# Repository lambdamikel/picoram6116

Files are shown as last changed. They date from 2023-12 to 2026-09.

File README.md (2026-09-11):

# picoram6116

A Raspberry Pi Pico (RP2040)-based 6161 SRAM Emulator, SD Card
Interface, and Multi-Expansion for the [Multitech Microprofessor
MPF-1B and MPF-1P SBCs (Single Board
Computers)](https://hackaday.io/project/183618-exploring-the-microprofessor).

Demo videos:

- [PicoRAM 6116 Review by "Mein Elektronik Hobby" (in German)](https://youtu.be/-fE-1R6At-s)

- [John's E&L MT-80Z MPF-1B variant with PicoRAM 6116](https://youtu.be/OmJJHkyRD8g)

- [Microprofessor MPF-1P Z80 PicoRAM 6116 and MPF-1P Printer - The Towers of Hanoi](https://youtu.be/8veR5Y--iOg)

- [Microprofessor MPF-1P Z80 Assembly Programming with PicoRAM 6116 - The Towers of Hanoi](https://youtu.be/II9slfHpY4s)

- [Microprofessor MPG-1(B) Z80 Assembly Programming with PicoRAM 6116 - The Towers of Hanoi](https://youtu.be/KoFRpU5a6iM)

- [PicoRAM 6116 Demo Video with MPF-1B / Rev. 3 PCB](https://youtu.be/Uu-U00VHX-8)

- [PicoRAM 6116 Demo Video with MPF-1P / Rev. 4 PCB](https://youtu.be/QXIxJ-ij4dM)

The [development
logs](https://hackaday.io/project/194092-picoram-6116-sram-emulator-sd-card-interface)
are on [Hackaday.](https://hackaday.com)

This project is a follow-up to [PicoRAM 2090 for the Busch Microtronic
Computer System](https://github.com/lambdamikel/picoram2090); also
see the [development logs on
Hackaday.](https://hackaday.io/project/192655-picoram-2090)

### PicoRAM 6116 with the MPF-1B - older PCB Rev. 3 

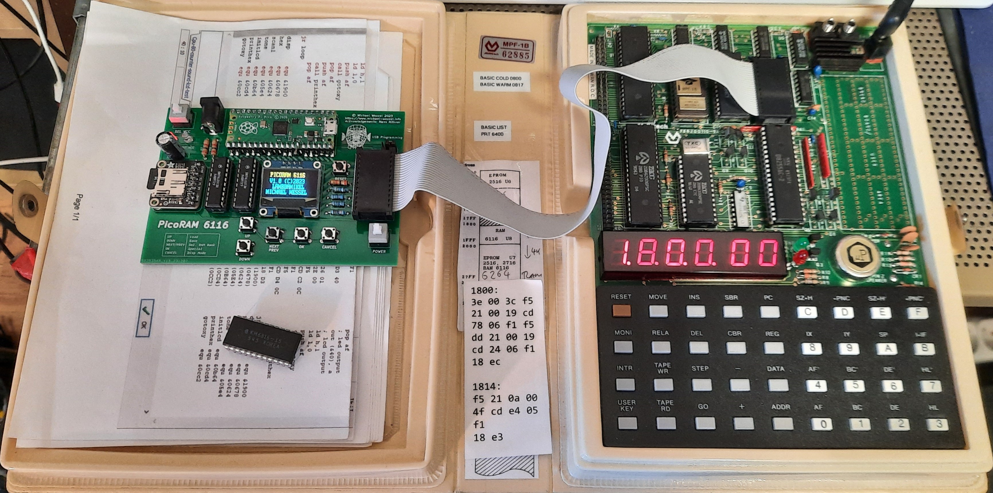
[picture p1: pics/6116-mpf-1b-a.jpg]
PicoRAM 6116 MPF-1B a


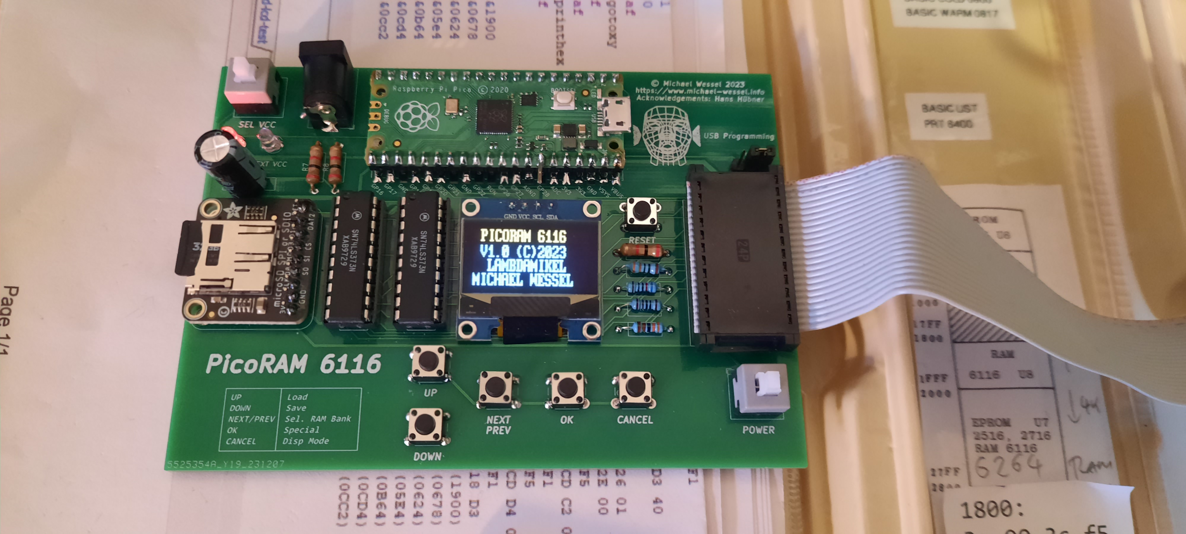
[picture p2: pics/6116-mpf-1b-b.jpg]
PicoRAM 6116 MPF-1B b


### PicoRAM 6116 with the MPF-1P (IP / One Plus) - current PCB Rev. 4 

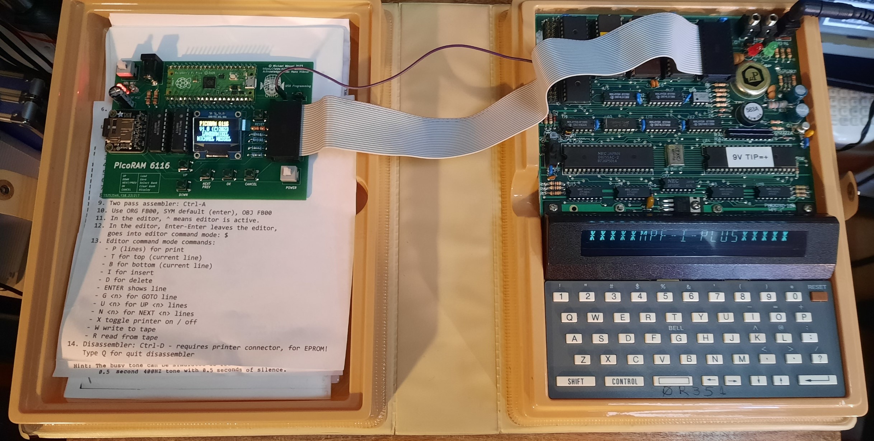
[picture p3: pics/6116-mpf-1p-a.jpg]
PicoRAM 6116 MPF-1P a


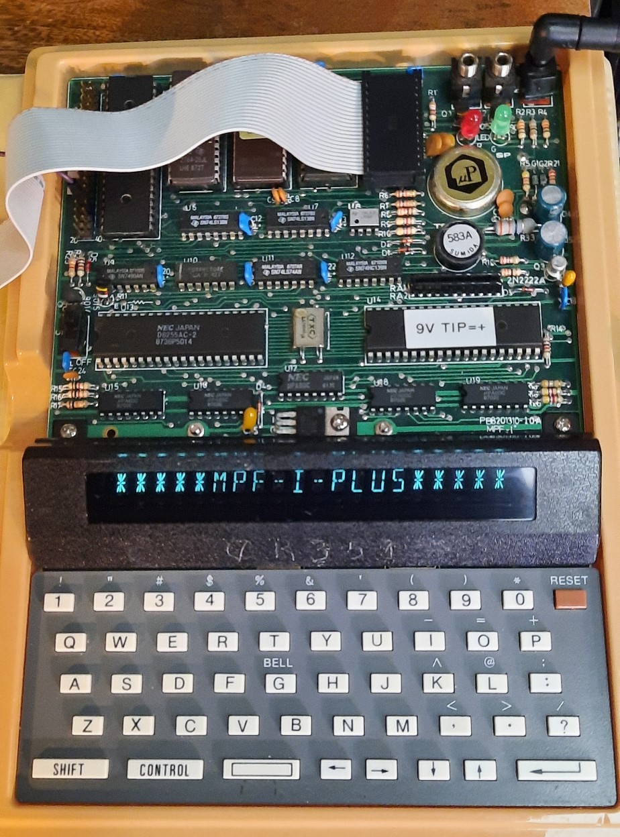
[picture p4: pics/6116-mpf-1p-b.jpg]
PicoRAM 6116 MPF-1P b


## Latest News

### October 2025

During my [RetroChallenge 2025/10
contribution](https://hackaday.io/project/204153-3d-graphics-on-the-microprofessor-mpf-1b),
I encountered a pretty nasty issue which took me quite a while to
debug and resolve. Mostly chasing red herrings. 

My [rotating 3D Cube](https://youtu.be/pLtGfMtQikc) was glitching, and
it took me a long time to realize that this was caused by noisy ADC
button decoding and inappropriate ADC level thresholds. The problem
was that this happened without visual feedback in the UI, so I was
unware of it. Now, for each detected button press, the SRAM emulation
is halted; and also for spurious button presses that don't cause an UI
action (the `CANCEL2` button was responsible). Now, halting the SRAM
emulation can only work properly if the Z80 WAIT signal is connected
to PicoRAM, which I had not in this case. Sometimes, I simply hold the
RESET button manually on the Microprofessor instead whilst operating
PicoRAM. Obviously, you can't just halt SRAM emulation and not halt
the CPU and expect it to run properly.

So, this problem was fixed by adjusting the ADC threshold levels in
the `6116.INI` file. However, I didn't like that the spurious button
presses weren't reported and happened "silently", leaving me unaware
of what was happening. In the UI loop code, there was no `switch case`
that caught this case, and a `default` clause was missing as well. I
have now added such a `default` clause. It will show an error message
on the display informing the user about inadequate ADC button
threshold levels in the init file that may cause SRAM emulation
glitches.

**Please install the [new firmware (Version
1.2).](firmware/sram6116_v1.2.uf2)**

## Older News

### October 2024

[PicoRAM 6116 build and demo video](https://youtu.be/-fE-1R6At-s) on
the YouTube channel "Mein Elektronik Hobby" (in German). Glad it
worked out flawlessly - thanks for the positive review, Werner!

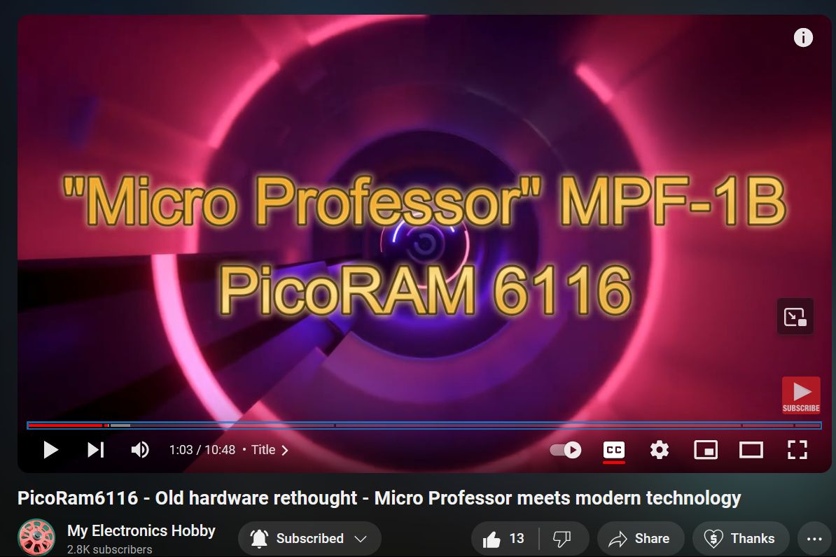
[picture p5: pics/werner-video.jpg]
Werner


### June 2024

John W. added PicoRAM 6116 to his E&L MT-80Z MPF-1B clone and, after
initial troubles, got it to work flawlessly. Very nice machine and 
progress - thanks for sharing, John! Good to know that PicoRAM 6116
also works well with the less common Microprofessor family members.

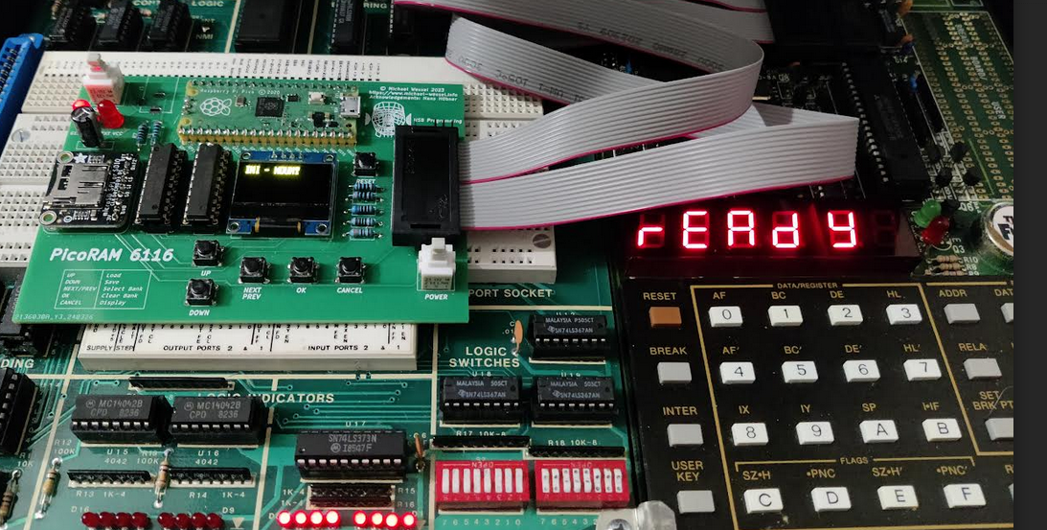
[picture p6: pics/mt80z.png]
MT80Z


### December 17th 2023

[Hackster covered the PicoRAM
6116.](https://www.hackster.io/news/michael-wessel-s-raspberry-pi-pico-powered-6116-sram-emulator-gives-vintage-sbcs-a-major-overhaul-2324810b773c)

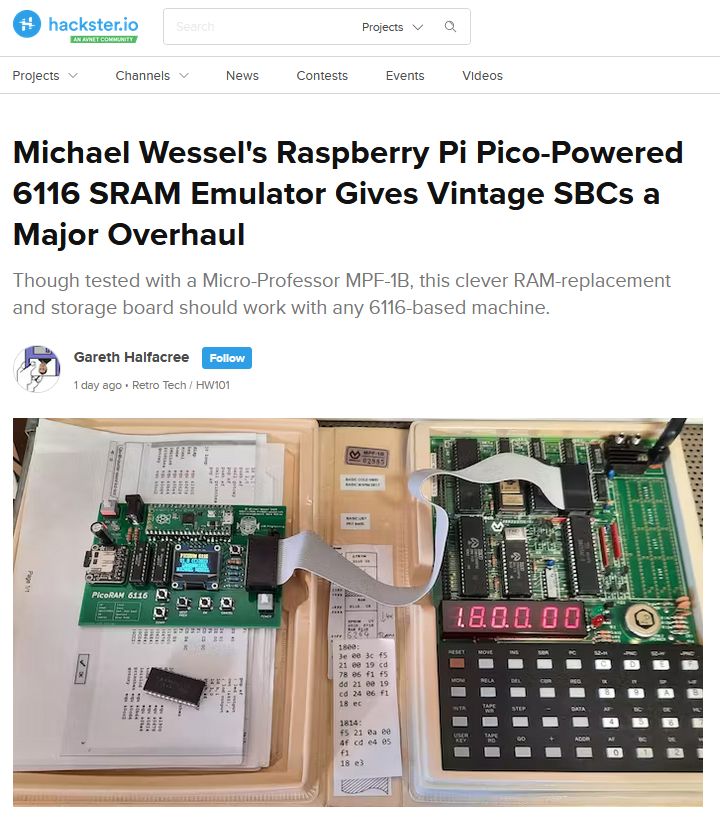
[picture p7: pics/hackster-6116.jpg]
Hackster


I also archived [the PDF of the Hackster article.](pics/hackster-article.pdf)

## About

**PicoRAM 6116 is the ultimate expansion for the vintage Microprofessor SBCs.**

Features:

- SD card interface: loading and saving of programs (full SRAM memory
  dumps) and easy file exchange with the PC (FAT32 filesystem). ASCII
  HEX format, additionally supporting comments and target addresses.

- Plugs into the U8 6116 socket on the MPF-1B
  (address range `0x1800 - 0x1FFF`) or the U5 6116 socket on the MPF-1P
  (address range `0xF800 - 0xFFFF`).

- Comfortable UI: 5 buttons and OLED display.

- 4 user memory banks: the currently active memory bank can selected
  over the UI; each bank hosts a full 6116 SRAM.

- Autoload feature: the `6116.INI` file is loaded during startup
  and allows the specification of an autoload program for each of the 4
  memory banks. 

- Easy build & installation: PicoRAM 6116 uses pre-assembled
  off-the-shelf modules and through-hole components only, and no
  (destructive) modifications to the Microprofessor are required.

## Usage

The JP1 Jumper should be in the right position:

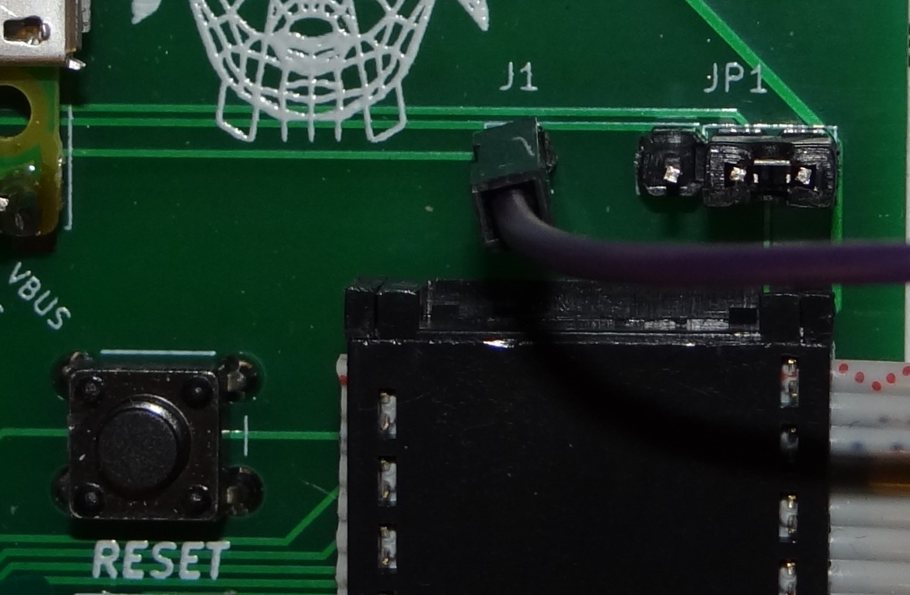
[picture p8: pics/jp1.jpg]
JP1 Jumper


The current version is PCB Rev. 4. This PCB hosts an extra single pin
connector (J1). Connect J1 to the Microprofessor's WAIT on the
expansion header (PIN 37):

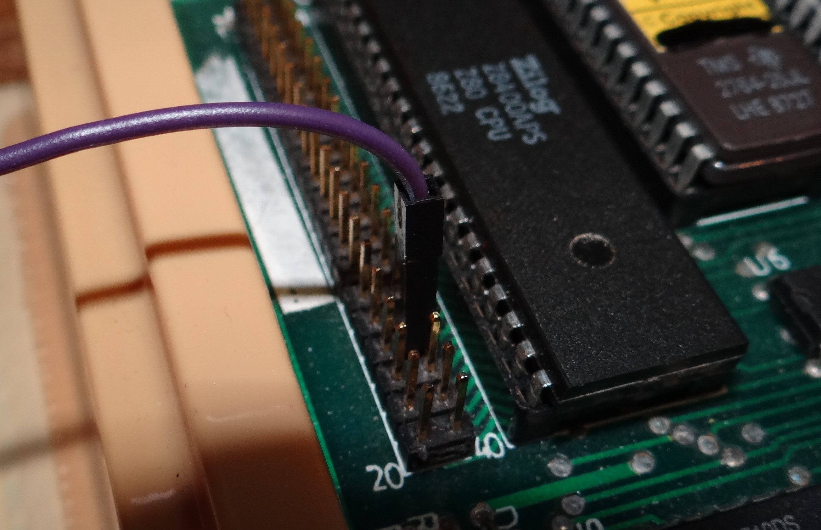
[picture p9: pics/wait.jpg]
WAIT


If you don't use the J1 to WAIT connection, you will need to hold the
Microprofessor in RESET while operating PicoRAM - see the [Rev. 3 Demo
Video](https://youtu.be/Uu-U00VHX-8).  However, this is no longer
required with Rev. 4 (the current version from this repository) - as
shown in [the Rev. 4 demo video](https://youtu.be/QXIxJ-ij4dM)). This
video shows the MPF-1P, but it also applies to the MPF-1B.

PicoRAM needs a FAT32-formatted (max 32 GB) Micro SD Card. Copy the
appropriate `6116.INI` file to it, and get the correct demo programs
for your machine (MPF-1B or MPF-1P). Unzip everything to the root
directory; sub-directories are not supported. See [this
directory.](software/)

PicoRAM 6116 is usually powered over the 6116 SRAM socket. Make sure
that the **POWER** button is pushed down, and that the **SEL VCC**
(Power Source) is set to **6116 VCC**. External power supply is
possible as well, using the 5V Center Positive Barrel Jack. However,
this should not be required. The LEDs **6116 VCC** and **EXT VCC**
light up indicating which power sources are available (i.e., if both
**EXT VCC** and **6116 VCC** light up, it means that you have power
over the 6116 Socket from the Microprofessors, as well as VCC from the
external power supply). Then, use the **SEL VCC** switch to determine
the utilized power source (either external or internal). If you have
an external power source connected, but **EXT VCC** stays dark, then
you probably have the wrong polarity.

### `6116.INI` File

The 5 UI buttons are using the Pico's analog input. Unfortunately, the 
analog levels turned out to be very noisy and also vary from machine
to machine. So it might be necessary for you to "tune" these
analog threshold levels to match your machine. The `6116.INI` file
supports this. The init file looks as follows for the MPF-1B
(not that UNIX EOL is required! a single newline / `0x0A` character):

```
MPF-1B
D00
C00
900
700
300
100
CLOCK.MPF
DICE2.MPF
COUNTER2.MPF
EGGTIME.MPF
0
```

The file lists, in this order:
- the name of the machine
- the analog threshold for the CANCEL buttons (used during YES/NO dialogues) 
- the 2nd analog threshold for the CANCEL buttons (toplevel buttons)
- the analog threshold for the OK button
- the analog threshold for the NEXT/PREV button
- the analog threshold for the UP button
- the analog threshold for the DOWN button
- 4 lines for the 4 autoload programs for banks 0 to 3 - use an empty line for no program
- 0 or 1; 0 for normal operation, and 1 is used to enter a debugging program which can be used to determine the above analog threshold for the buttons above.

Note that the default init files for the MPF-1B and MPF-1P are
supplied, and that the analog thresholds differ. They were determined
with the author's machines, and might not work for your machine.

## Theory of Operation

The Pico emulates the 6116 SRAM of the Microprofessor:

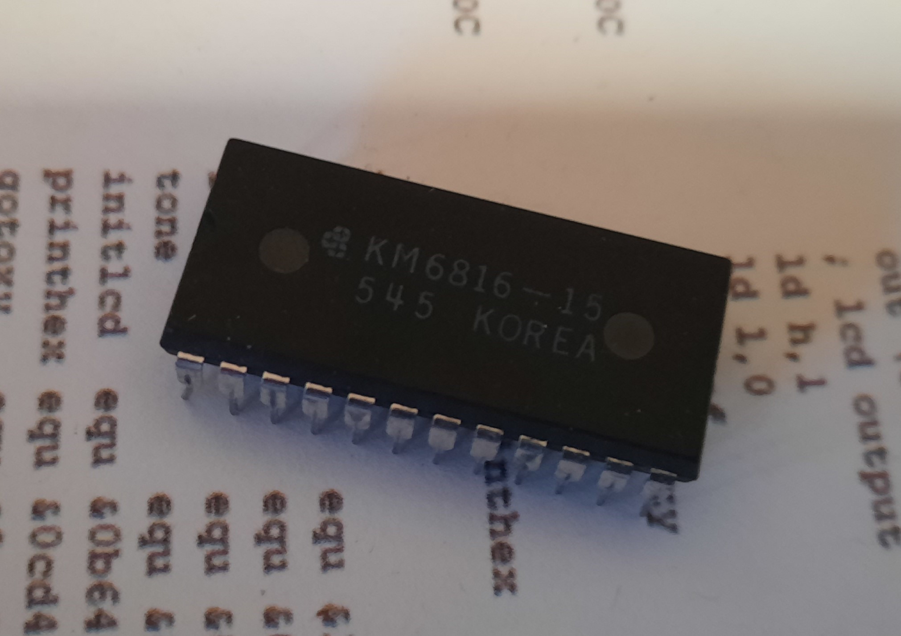
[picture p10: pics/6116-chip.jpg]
6116 Chip


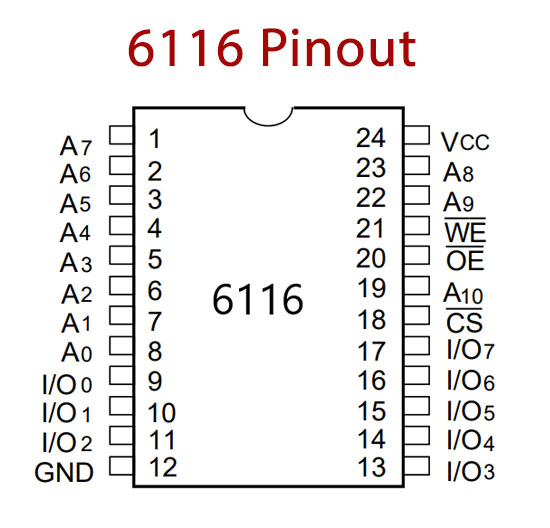
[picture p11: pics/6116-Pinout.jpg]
6116 Pinout


The Pico is overclocked to 250 Mhz to make this possible; this
is completely in the safe range and does not affect the longevity
of the RP2040 in any negative way. 

Due to a lack of GPIOs on the Pico, I used two 74LS373 transparent
octal latches to multiplex the 11-bit address bus. The 11-bit address
is read in two batches of 6 and 5 bits, using the `SEL1` and `SEL2`
signals from the Pico to OE (Output Enable) the first resp. second
latch. The latches are merely used for their tri-state capabilities.

Unlike my previous design, [PicoRAM
2090](https://github.com/lambdamikel/picoram2090), this design does
not utilize any voltage level converters.  It turns out that the Pico
(RP2040) is really pretty much 5V-tolerant; also see [this article
from
Hackaday](https://hackaday.com/2023/04/05/rp2040-and-5v-logic-best-friends-this-fx9000p-confirms/)
and the [Hackaday coverage of PicoRAM
2090.](https://hackaday.com/2023/09/10/pi-pico-becomes-sram-for-1981-educational-computer/)

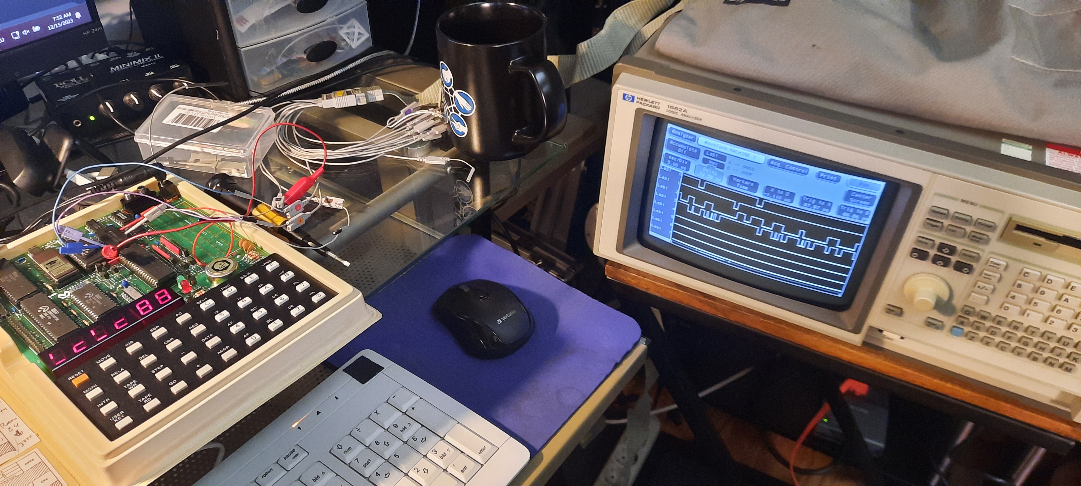
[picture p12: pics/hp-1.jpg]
HP Logic Analyzer 1


More details about the making of the project, and technical notes / development log can be found on the [Hackaday project page.](https://hackaday.io/project/194092-picoram-6116-sram-emulator-sd-card-interface)

Schematics:

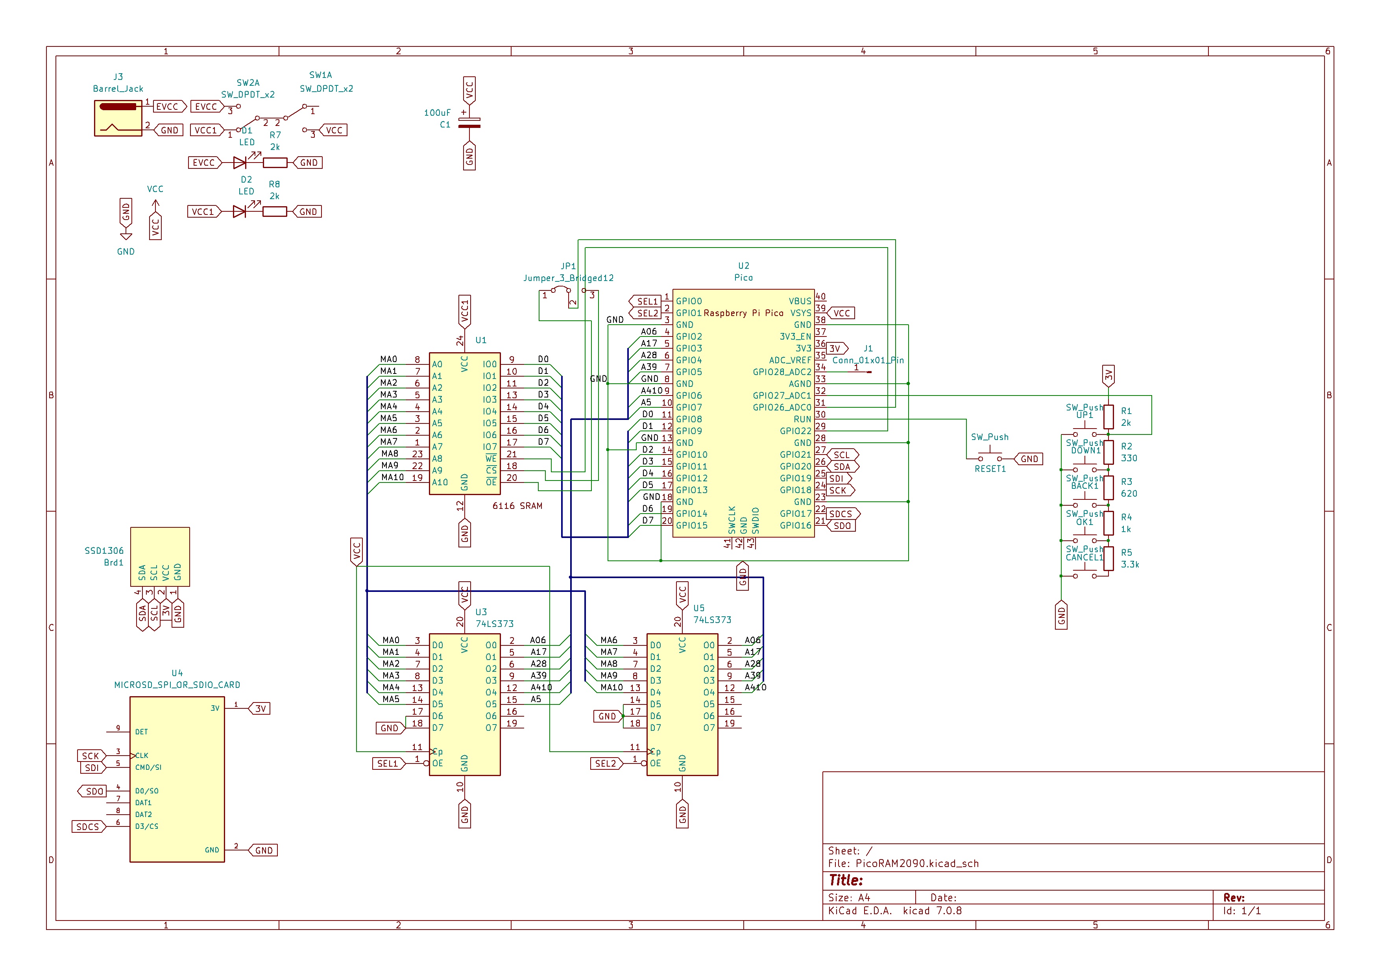
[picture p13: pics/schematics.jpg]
Schematics


## PCB

The current version is Rev. 4, December 2023.

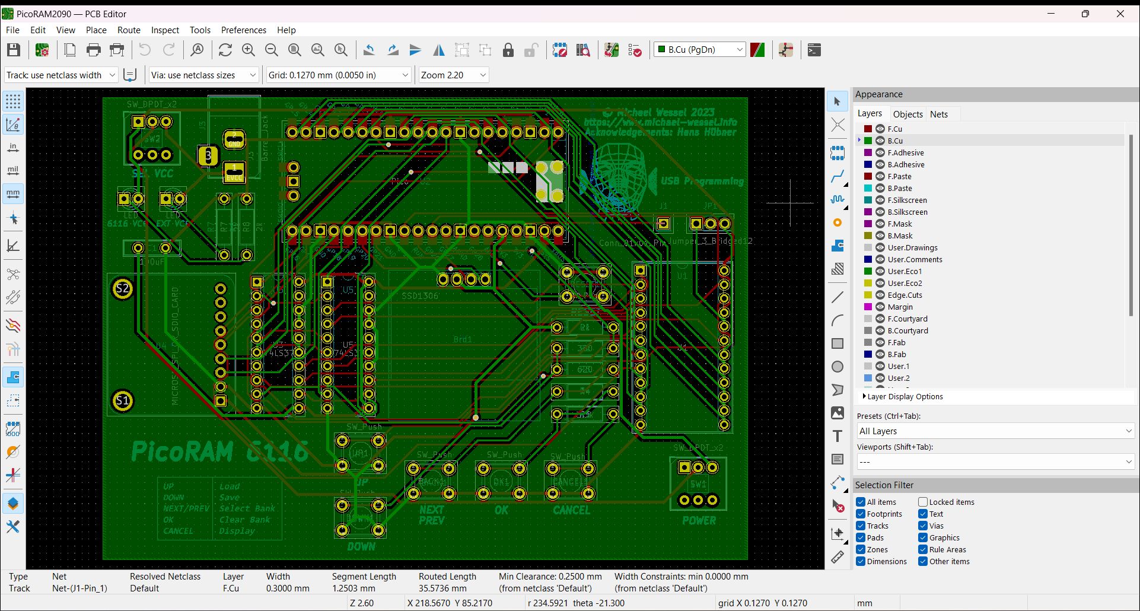
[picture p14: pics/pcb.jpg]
PCB


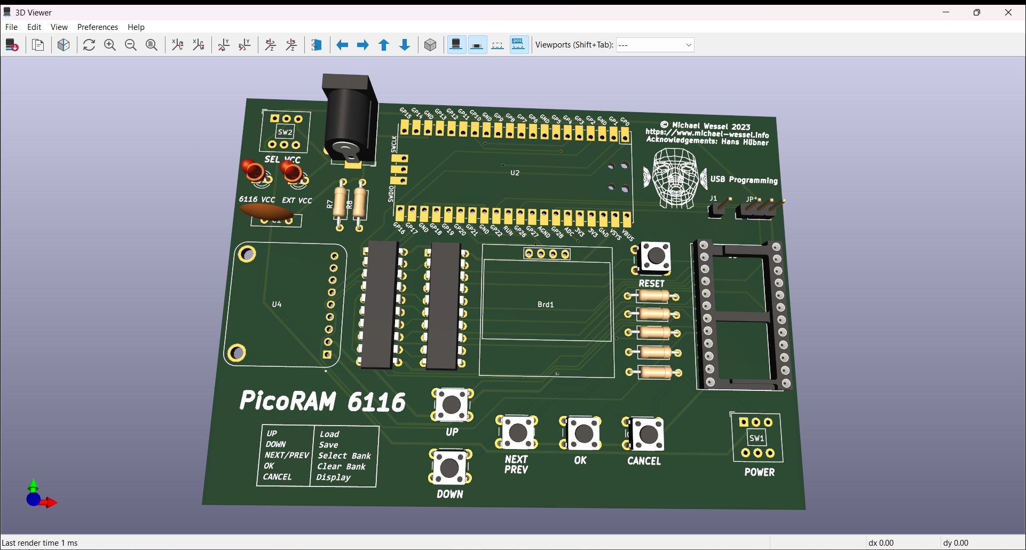
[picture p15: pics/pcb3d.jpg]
PCB 3D


There is also a [Bill of Material (BOM).](gerbers/PicoRAM6116.csv) 

### Gerbers 

See [here.](gerbers/PicoRAM6116-Gerbers.zip) 

## Firmware Image

The current version is 1.1, December 2023 and the `.uf2` image can be
found [here.](firmware/v1.1/sram6116.uf2)

## Firmware Sources

See [here.](src/)

## Acknowledgements

- Harry Fairhead for his [excellent
  book!](https://www.amazon.com/gp/product/1871962056)

- Hans Hübner (aka Pengo) for motivating me to abandon the BluePill,
ATmegas and Arduinos, and for helping to get started and
troubleshooting!

- The authors of the libraries that I am using:

  - Carl J Kugler III carlk3:
    [https://github.com/carlk3/no-OS-FatFS-SD-SPI-RPi-Pico](https://github.com/carlk3/no-OS-FatFS-SD-SPI-RPi-Pico)

  - Raspberry Pi Foundation for the `ssd1306_i2c.c` demo.

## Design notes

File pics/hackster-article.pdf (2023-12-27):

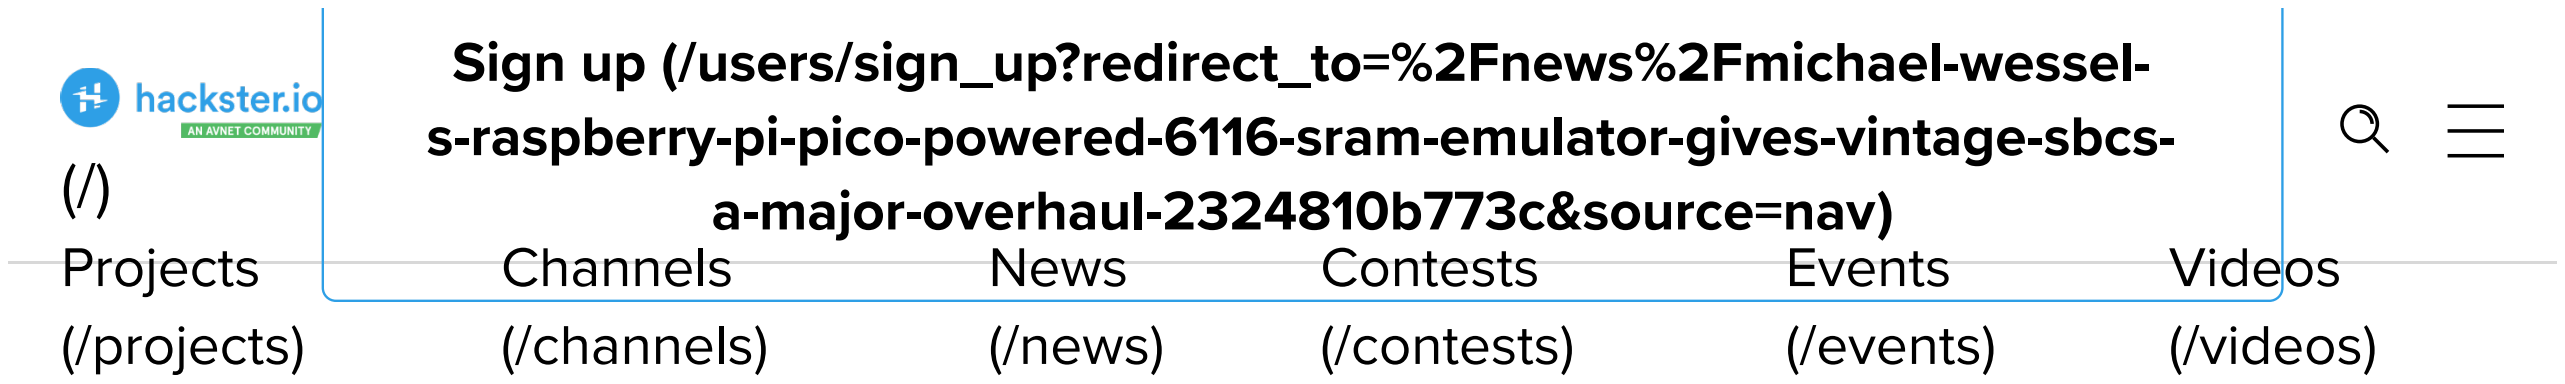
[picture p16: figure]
Sign up (/users/sign_up?redirect_to=%2Fnews%2Fmichael-wessel- s-raspberry-pi-pico-powered-6116-sram-emulator-gives-vintage-sbcs- a-major-overhaul-2324810b773c&source=nav); Projects (/projects); Channels (/channels); News (/news); Contests (/contests); Events (/events); Videos (/videos)

# Michael Wessel's Raspberry Pi Pico-Powered 6116 SRAM Emulator Gives Vintage SBCs a Major Overhaul

## Though tested with a Micro-Professor MPF-1B, this clever RAMreplacement and storage board should work with any 6116-based

machine.

(/ghalfacree)

Gareth Halfacree (/ghalfacree) (https://www.hackster.io/ghalfacree) Follow

1 day ago • Retro Tech (https://www.hackster.io/retrotech) / HW101 (https://www.hackster.io/hw101) (https://www.hackster.io/hw101)

Michael Wessel's Raspberry Pi Pico-Powered 6116 SRAM Emulator Gi... | https://www.hackster.io/news/michael-wessel-s-raspberry-pi-pico-powe...

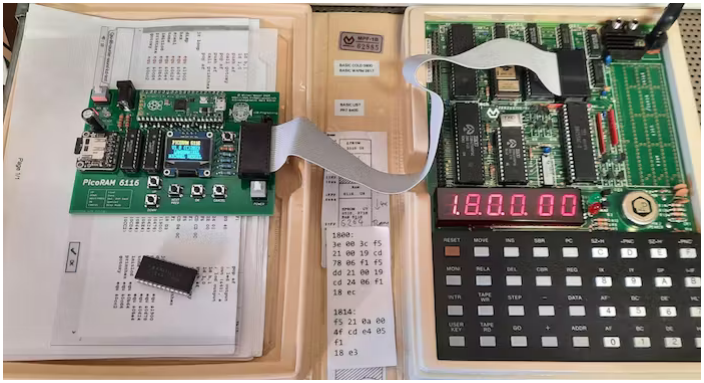
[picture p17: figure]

1 of 8 | 12/19/2023, 6:34 PM

(https://hubs.li/Q02cBMp60)
Ad (http://help.hackster.io/knowledgebase/what-are-these-ads) (http://help.hackster.io/knowledgebase/what-are-these-ads)

Vintage computing enthusiast Michael Wessel has turned a Raspberry Pi Pico into static RAM (SRAM) emulator and SD card storage interface for the Multitech Micro-Professor MPF-1B — bringing with it some serious quality-oflife bonuses.

"Give your Micro-Professor MPF-1B (and other machines) a versatile SD card interface — no more cassettes," Wessel writes of his creation. "Emulate 2kBs of 6116 SRAM with a Raspberry Pi Pico and use an SD card for storing and loading full memory dumps! Its first use case is to emulate the U8 2kB system RAM from 0x1800 to 0x1FFF on the Micro-Professor MPF-1B. You won't need the cassette interface any longer — just use the SD card."

If you've a vintage computer built around 6116 SRAM chips, this Raspberry Pi Pico-powered add-on is exactly what you need. (

: Michael Wessel)

Launched in 1981 by Multitech, which still makes computers today under the more recognizable name Acer, the Micro-Professor MPF-I was a Zilog Z80-based single-board computer which aimed to teach the core concepts of programming for the chip. The device's output was shown on a six-digit seven-segment display, while programs could be saved — slowly — to cassette tape.

It's this slow storage medium Wessel's creation replaces, bypassing the machine's own storage system in order to load and save directly to RAM near-instantaneously — by using a Raspberry Pi Pico's RP2040 microcontroller to emulate the machine's original 2kB RAM chip.

Getting the device up and running proved a challenge — not least of all due to a lack of GPIO pins. (

: Michael Wessel)

"The first challenge was a lack of GPIO [General-Purpose Input/Output] pins on the Pico," Wessel writes of the project. "The 6116 [SRAM chip demands] a whooping eight bits of data IO, 11 bits for the address bus, plus OE [Output Enable] and WE [Write Enable] — 21 GPIOs of the max. 26 that the Pico offers."

Given that Wessel also wanted to offer a user interface with an OLED display, and storage on an SD card slot, additional GPIO pins were required — which were provided through multiplexing the address bus using two 74LS373 eightbit latches. "The two latches are basically just used for their tri-state/High-Z ability," Wessel explains, "I am not even using them as latches."

The device provides the ability to load and save full 2kB memory dumps near-instantaneously from microSD storage. (

: Michael Wessel)

This isn't the first device Wessel has built from a Raspberry Pi Pico in order to offer quality-of-life improvements for vintage computers. Back in September he unveiled an add-on for the Busch 2090 Microtronic Computer System (https://www.hackster.io/news/michael-wessel-turns-a-raspberry-pi-pico-intoan-add-on-for-the-four-bit-busch-2090-microtronic-sbc-c21abaff56bd), (https://www.hackster.io/news/michael-wessel-turns-a-raspberry-pi-pico-into-an-add-on-for-the-four-bit-busch-2090-microtronic-sbc-c21abaff56bd) the PicoRAM 2090, which aimed to work around the device's painfully slow 14-baud cassette interface with microSD storage.

The final device works perfectly on a real Multitech Micro-Professor MPF-1B — even pulling its power from the host system directly — and, Wessel notes, should also work "with other 6116-based computers." More information on the project is available on Wessel's Hackaday.io page (https://hackaday.io/project/194092-picoram-6116-sram-emulator-sd-card-interface). (https://hackaday.io/project/194092-picoram-6116-sram-emulator-sd-card-interface)

sd card (https://www.hackster.io/projects/tags/sd+card)

retro (https://www.hackster.io/projects/tags/retro)

single board computer (https://www.hackster.io/projects/tags/single+board+computer)

microcontroller (https://www.hackster.io/projects/tags/microcontroller)

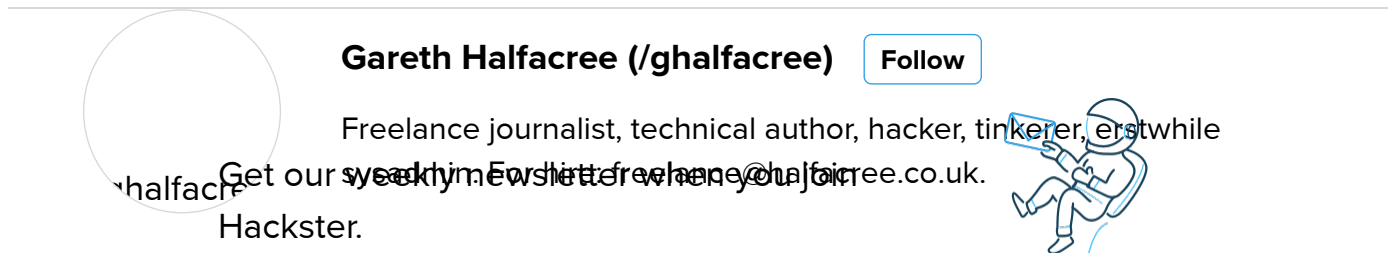
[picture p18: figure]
(/ghalfacree); Gareth Halfacree (/ghalfacree) Follow; sysadmin. For hire: freelance@halfacree.co.uk.; Get our weekly newsletter when you join Hackster.

Freelance journalist, technical author, hacker, tinkerer, erstwhile

SPONSORED ARTICLES

Iván Arakistain Wins the Top Connect for Good Prize for an Emissions-Slashing Nordic nRF9160 Gadget
(https://www.hackster.io/news/ivan-arakistain-wins-the-top-connect-forgood-prize-for-an-emissions-slashing-nordic-nrf9160-gadget-818618ec7ac6) (https://www.hackster.io/news/ivan-arakistain-wins-the-top-connect-for-good-prize-for-an-emissions-slashing-nordic-nrf9160-gadget-818618ec7ac6)
Sponsored by Nordic Semiconductor (https://www.nordicsemi.com)

Revitalizing Nantou Ancient Town: A Co-Creation Adventure (https://www.hackster.io/news/revitalizing-nantou-ancient-town-a-co-creation-adventure-c45f8fc0c7fb) (https://www.hackster.io/news/revitalizing-nantou-ancient-town-a-co-creation-adventure-c45f8fc0c7fb)
Sponsored by Seeed Studio (https://www.seeedstudio.com)

Sign up

LATEST ARTICLES (https://www.hackster.io/news/ivan-arakistain-wins-the-top-connect-for-good-prize-for-an-emissions-slashing-nordic-nrf9160-gadget-818618ec7ac6) | Read more (/news?ref=ha_rm_btn) (https://www.hackster.io/news?ref=ha_rm_btn)

(https://
www.ha
ckster.io (https://www.hackster.io/news/ivan-arakistain-wins-the-top-connect-for-good-prize-for-an-emissions-slashing-nordic-nrf9160-gadget-818618ec7ac6)

(https://
www.ha
ckster.io (https://www.hackster.io/news/revitalizing-nantou-ancient-town-a-co-creation-adventure-c45f8fc0c7fb)

RELATED ARTICLES

Artur Pękosz's Palm-Sized Quadcopter Drone Uses a Single-Camera Raspberry Pi for FPV and Recording (https://www.hackster.io/news/artur-pekosz-s-palm-sized-quadcopterdrone-uses-a-single-camera-raspberry-pi-forfpv-and-recording-27243ca5b27a) (https://www.hackster.io/news/artur-pekosz-s-palm-sized-quadcopter-drone-uses-a-single-camera-raspberry-pi-for-fpv-and-recording-27243ca5b27a)
Gareth Halfacree (/ghalfacree) (https://www.hackster.io/ghalfacree) • 13 hours ago

Sonocotta's Esparagus HiFi MediaLink Puts an Espressif ESP32 to Work Upgrading Your Old Hi-Fi (https://www.hackster.io/news/sonocotta-s-esparagus-hifi-medialinkputs-an-espressif-esp32-to-work-upgradingyour-old-hi-fi-be50297e41ef) (https://www.hackster.io/news/sonocotta-s-esparagus-hifi-medialink-puts-an-espressif-esp32-to-work-upgrading-your-old-hi-fi-be50297e41ef)
Gareth Halfacree (/ghalfacree) (https://www.hackster.io/ghalfacree) • 14 hours ago

This Micro Nissan Micra Is a 1/150th Scale Model That Actually Drives, Thanks to Under-Road Wiring (https://www.hackster.io/news/this-micro-nissan-micra-is-a-1-150thscale-model-that-actually-drives-thanks-tounder-road-wiring-5d7cff6b2c8c) (https://www.hackster.io/news/this-micro-nissan-micra-is-a-1-150th-scale-model-that-actually-drives-thanks-to-under-road-wiring-5d7cff6b2c8c)
Gareth Halfacree (/ghalfacree) (https://www.hackster.io/ghalfacree) • 15 hours ago

A Deep Dive Into Reinforcement Learning (https://www.hackster.io/news/a-deep-diveinto-reinforcement-learning-f1aa70f3276a) (https://www.hackster.io/news/a-deep-dive-into-reinforcement-learning-f1aa70f3276a)
Nick Bild (/nickbild) (https://www.hackster.io/nickbild) • 1 day ago

(https://www.hackster.io/news/arturpekosz-s-palm-sized-quadcopter-droneuses-a-single-camera-raspberry-pi-for-fpvand-recording-27243ca5b27a) (https://www.hackster.io/news/artur-pekosz-s-palm-sized-quadcopter-drone-uses-a-single-camera-raspberry-pi-for-fpv-and-recording-27243ca5b27a)

(https://www.hackster.io/news/sonocottas-esparagus-hifi-medialink-puts-anespressif-esp32-to-work-upgrading-yourold-hi-fi-be50297e41ef) (https://www.hackster.io/news/sonocotta-s-esparagus-hifi-medialink-puts-an-espressif-esp32-to-work-upgrading-your-old-hi-fi-be50297e41ef)

(https://www.hackster.io/news/this-micronissan-micra-is-a-1-150th-scale-modelthat-actually-drives-thanks-to-under-roadwiring-5d7cff6b2c8c) (https://www.hackster.io/news/this-micro-nissan-micra-is-a-1-150th-scale-model-that-actually-drives-thanks-to-under-road-wiring-5d7cff6b2c8c)

(https://www.hackster.io/news/a-deepdive-into-reinforcement-learningf1aa70f3276a) (https://www.hackster.io/news/a-deep-dive-into-reinforcement-learning-f1aa70f3276a)

Matt Callow Turns a Raspberry Pi Pico Into a Low-Cost ROM Emulator for the Amstrad CPC Family (https://www.hackster.io/news/matt-callow-turns-a-raspberry-pi-picointo-a-low-cost-rom-emulator-for-theamstrad-cpc-family-cd82e984b9f8) (https://www.hackster.io/news/matt-callow-turns-a-raspberry-pi-pico-into-a-low-cost-rom-emulator-for-the-amstrad-cpc-family-cd82e984b9f8)
Gareth Halfacree (/ghalfacree) (https://www.hackster.io/ghalfacree) • 8 months ago

Konrad Beckmann's Raspberry Pi Pico-Powered Adapter Gives the Nintendo 64 an HDMI Video Output (https://www.hackster.io/news/konrad-beckmann-s-raspberry-pi-pico-powered-adapter-gives-the-nintendo-64-an-hdmi-video-output-f10600bb3ea5) (https://www.hackster.io/news/konrad-beckmann-s-raspberry-pi-pico-powered-adapter-gives-the-nintendo-64-an-hdmi-video-output-f10600bb3ea5)
Gareth Halfacree (/ghalfacree) (https://www.hackster.io/ghalfacree) • 9 months ago

Raspberry Pi Launches New Debian 12 "Bookworm" Raspberry Pi OS, Ready for Raspberry Pi 5 (https://www.hackster.io/news/raspberry-pi-launches-new-debian-12-bookworm-raspberry-pi-os-ready-forraspberry-pi-5-611ead3e4103) (https://www.hackster.io/news/raspberry-pi-launches-new-debian-12-bookworm-raspberry-pi-os-ready-for-raspberry-pi-5-611ead3e4103)
Gareth Halfacree (/ghalfacree) (https://www.hackster.io/ghalfacree) • 2 months ago (https://www.hackster.io/privacy/ccpa)

An Ultra-Tiny RISC-V Emulator Turns the Raspberry Pi Pico Into a Functional, If Slow, Linux PC (https://www.hackster.io/news/an-ultra-tiny-risc-v-emulator-turns-the-raspberry-pi-pico-into-a-functional-if-slow-linuxpc-17493d4d7130) (https://www.hackster.io/news/an-ultra-tiny-risc-v-emulator-turns-the-raspberry-pi-pico-into-a-functional-if-slow-linux-pc-17493d4d7130)
Gareth Halfacree (/ghalfacree) (https://www.hackster.io/ghalfacree) • 7 months ago

(https://www.hackster.io/news/mattcallow-turns-a-raspberry-pi-pico-intoa-low-cost-rom-emulator-for-the-amstradcpc-family-cd82e984b9f8) (https://www.hackster.io/news/matt-callow-turns-a-raspberry-pi-pico-into-a-low-cost-rom-emulator-for-the-amstrad-cpc-family-cd82e984b9f8)

(https://www.hackster.io/news/konradbeckmann-s-raspberry-pi-pico-poweredadapter-gives-the-nintendo-64-an-hdmivideo-output-f10600bb3ea5) (https://www.hackster.io/news/konrad-beckmann-s-raspberry-pi-pico-powered-adapter-gives-the-nintendo-64-an-hdmi-video-output-f10600bb3ea5)

(https://www.hackster.io/news/raspberry-pi-launches-new-debian-12-bookwormraspberry-pi-os-ready-for-raspberry-pi-5-611ead3e4103) (https://www.hackster.io/news/raspberry-pi-launches-new-debian-12-bookworm-raspberry-pi-os-ready-for-raspberry-pi-5-611ead3e4103)

(https://www.hackster.io/news/an-ultra-tiny-risc-v-emulator-turns-the-raspberry-pi-pico-into-a-functional-if-slow-linuxpc-17493d4d7130) (https://www.hackster.io/news/an-ultra-tiny-risc-v-emulator-turns-the-raspberry-pi-pico-into-a-functional-if-slow-linux-pc-17493d4d7130)

NEXT ARTICLE
Open Melt Is a "Melty Brain" Translatio…

(https://www.hackster.io
/news/open-melt-isa-melty-braintranslational-drift-robotspinning-like-a-remotecontrol-beyblade-8090c801724e (https://www.hackster.io/news/open-melt-is-a-melty-brain-translational-drift-robot-spinning-like-a-remote-control-beyblade-8090c801724e) About Us

Hackster Overview (/about)
Hackster for Business
(/business) (https://www.hackster.io/news/raspberry-pi-launches-new-debian-12-bookworm-raspberry-pi-os-ready-for-raspberry-pi-5-611ead3e4103)
Help Articles (https://www.hackster.io/ghalfacree)
(https://help.hackster.io) Brand Resources (/branding) (https://www.hackster.io/branding) Sitemap (/sitemap.xml.html) (https://www.hackster.io/sitemap.xml.html)

Legal Thingies

Terms of Service (/ter (https://www.hackster.io/news/raspberry-pi-launches-new-debian-12-bookworm-raspberry-pi-os-ready-for-raspberry-pi-5-611ead3e4103)ms) (https://www.hackster.io/terms)
Code of Conduct (/co (https://www.hackster.io/news/raspberry-pi-launches-new-debian-12-bookworm-raspberry-pi-os-ready-for-raspberry-pi-5-611ead3e4103)nduc (https://www.hackster.io/conduct)t) (https://www.hackster.io/news/an-ultra-tiny-risc-v-emulator-turns-the-raspberry-pi-pico-into-a-functional-if-slow-linux-pc-17493d4d7130) Privacy Policy (/privac (https://www.hackster.io/news/raspberry-pi-launches-new-debian-12-bookworm-raspberry-pi-os-ready-for-raspberry-pi-5-611ead3e4103)y) (https://www.hackster.io/privacy)
Privacy Policy for Californi (https://www.hackster.io/privacy/ccpa)a (https://www.hackster.io/ghalfacree) Residents (/privacy/ccpa) (https://www.hackster.io/privacy/ccpa)
Cookie Policy (/cookies) (https://www.hackster.io/cookies)

Find Us On Social

- Facebook
(https://www.facebook.com
/hacksterio) (https://www.hackster.io/news/an-ultra-tiny-risc-v-emulator-turns-the-raspberry-pi-pico-into-a-functional-if-slow-linux-pc-17493d4d7130)
- Instagram (https://www.hackster.io/ghalfacree)
(https://www.instagram.com/hacksterio) (https://www.instagram.com/hacksterio)
- LinkedIn
(https://www.linkedin.com
/company/hacksterio) (https://www.linkedin.com/company/hacksterio)
- Twitter
(https://www.twitter.com
/hacksterio) (https://www.twitter.com/hacksterio)
- YouTube (https://www.youtube.com/hacksterio)

(https://www.youtube.com
/hacksterio) (https://www.youtube.com/hacksterio)

Visit Our Avnet Family

Avnet (https://www.avnet.com) Premier Farnell
(https://www.farnell.com)
element14
(https://www.element14.com)
Newark
(https://www.newark.com) | Hackster.io, an Avnet Community © 2023

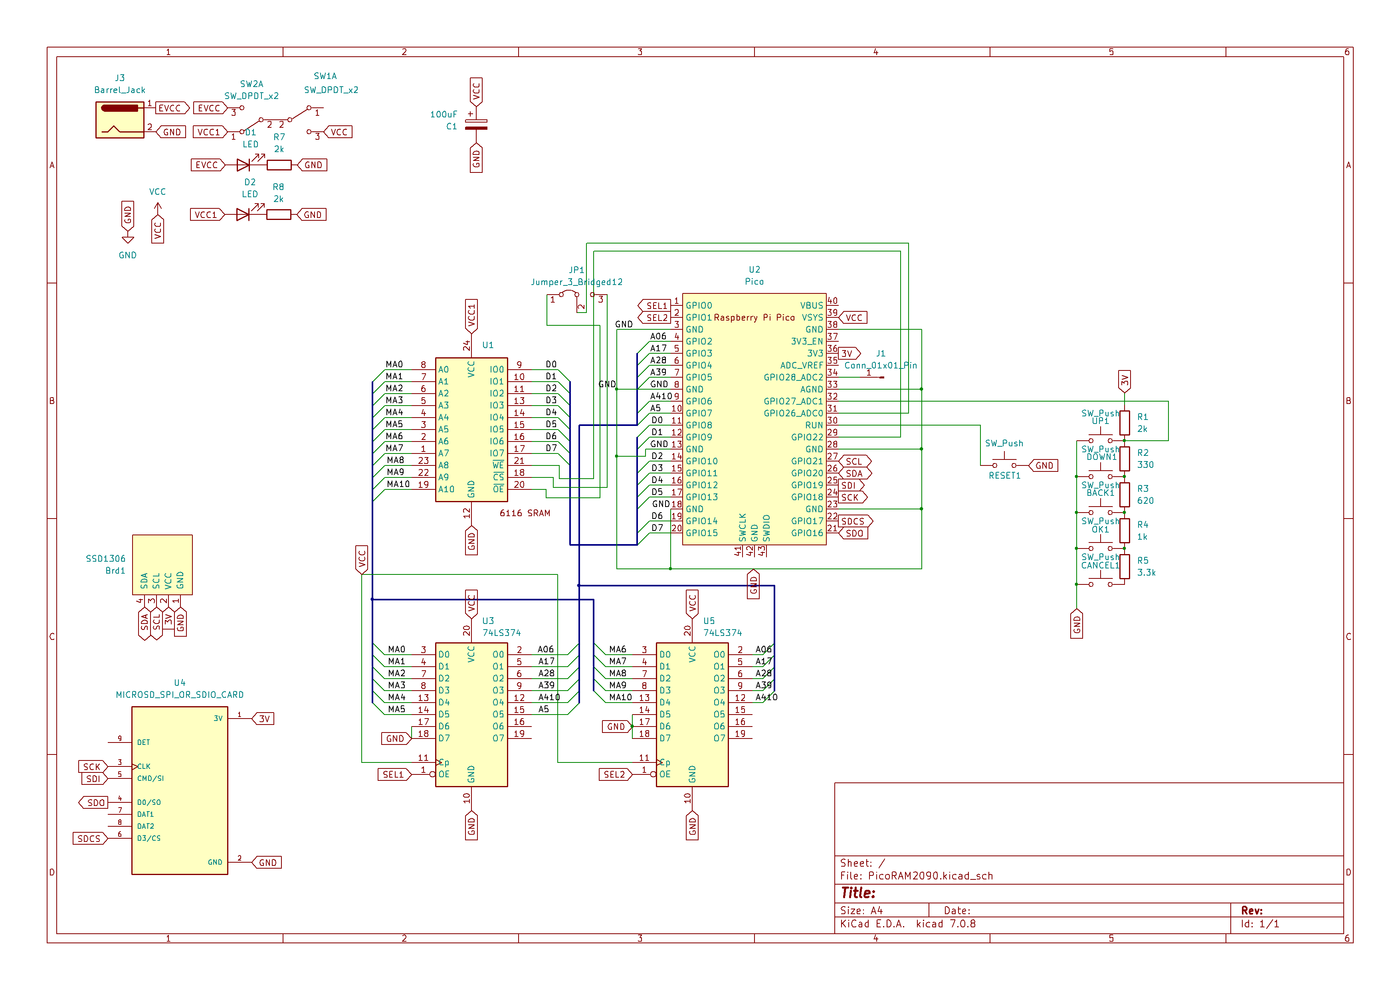
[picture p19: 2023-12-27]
pics/schematics.png

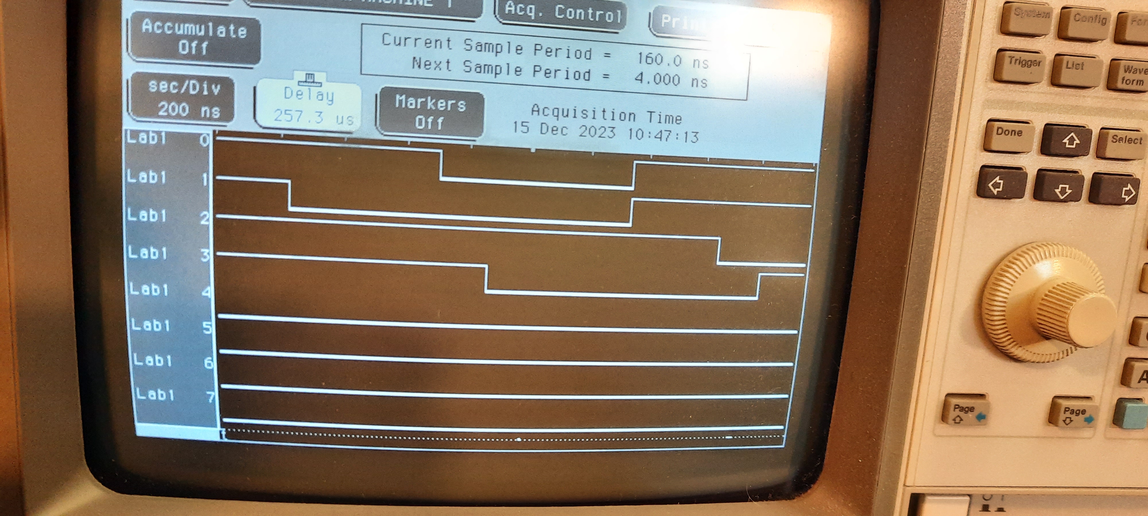
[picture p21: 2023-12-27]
pics/hp-3.jpg

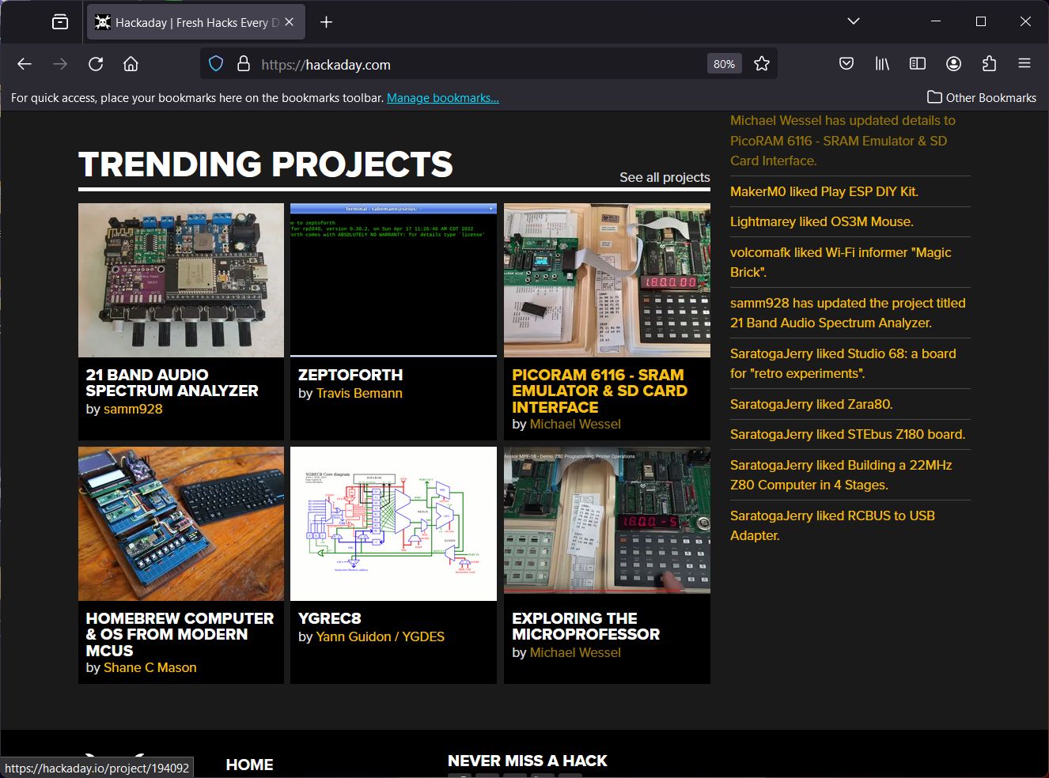
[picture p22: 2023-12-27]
pics/hackaday-12-17-2023-microprofessor-double-feature.jpg

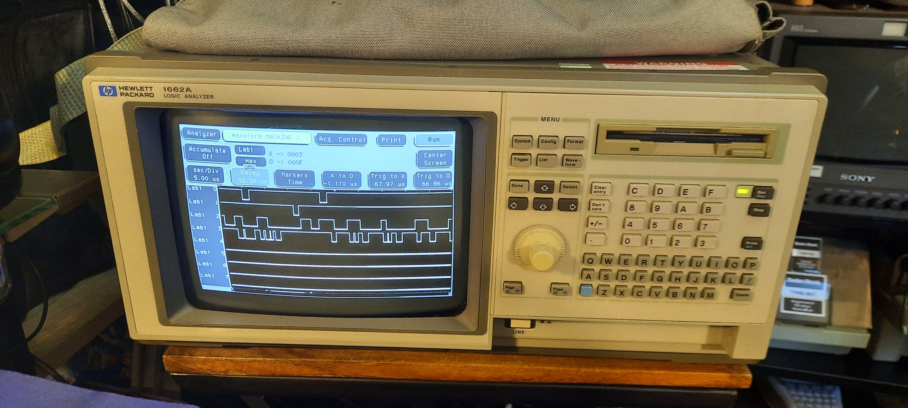
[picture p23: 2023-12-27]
pics/hp-2.jpg

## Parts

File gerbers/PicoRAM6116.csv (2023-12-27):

Source: | C:\Users\micha\Documents\PicoRAM 6116\PicoRAM2090.kicad_sch
Date: | 12/17/2023 8:08:53 AM
Tool: | Eeschema 7.0.8
Generator: | C:\Program Files\KiCad\7.0\bin\scripting\plugins/bom_csv_grouped_by_value_with_fp.py
Component Count: | 27
Ref | Qnty | Value | Cmp name | Footprint | Description | Vendor | DNP
BACK1 | 1 | SW_Push | SW_Push | Button_Switch_THT:SW_PUSH_6mm | Push button switch, generic, two pins
Brd1 | 1 | SSD1306 | SSD1306 | SSD1306:128x64OLED | SSD1306 OLED
C1 | 1 | 100uF | C_Polarized | Capacitor_THT:C_Disc_D10.0mm_W2.5mm_P5.00mm | Polarized capacitor
CANCEL1 | 1 | SW_Push | SW_Push | Button_Switch_THT:SW_PUSH_6mm | Push button switch, generic, two pins
D1, D2 | 2 | LED | LED | LED_THT:LED_D3.0mm | Light emitting diode
DOWN1 | 1 | SW_Push | SW_Push | Button_Switch_THT:SW_PUSH_6mm | Push button switch, generic, two pins
J1 | 1 | Conn_01x01_Pin | Conn_01x01_Pin | Connector_PinHeader_2.54mm:PinHeader_1x01_P2.54mm_Vertical | Generic connector, single row, 01x01, script generated
J3 | 1 | Barrel_Jack | Barrel_Jack | Connector_BarrelJack:BarrelJack_Horizontal | DC Barrel Jack
JP1 | 1 | Jumper_3_Bridged12 | Jumper_3_Bridged12 | Connector_PinHeader_2.54mm:PinHeader_1x03_P2.54mm_Vertical | Jumper, 3-pole, pins 1+2 closed/bridged
OK1 | 1 | SW_Push | SW_Push | Button_Switch_THT:SW_PUSH_6mm | Push button switch, generic, two pins
R1, R7, R8 | 3 | 2k | R | Resistor_THT:R_Axial_DIN0207_L6.3mm_D2.5mm_P10.16mm_Horizontal | Resistor
R2 | 1 | 330 | R | Resistor_THT:R_Axial_DIN0207_L6.3mm_D2.5mm_P10.16mm_Horizontal | Resistor
R3 | 1 | 620 | R | Resistor_THT:R_Axial_DIN0207_L6.3mm_D2.5mm_P10.16mm_Horizontal | Resistor
R4 | 1 | 1k | R | Resistor_THT:R_Axial_DIN0207_L6.3mm_D2.5mm_P10.16mm_Horizontal | Resistor
R5 | 1 | 3.3k | R | Resistor_THT:R_Axial_DIN0207_L6.3mm_D2.5mm_P10.16mm_Horizontal | Resistor
RESET1 | 1 | SW_Push | SW_Push | Button_Switch_THT:SW_PUSH_6mm | Push button switch, generic, two pins
SW1, SW2 | 2 | SW_DPDT_x2 | SW_DPDT_x2 | Button_Switch_THT:SW_Push_2P2T_Toggle_CK_PVA2OAH5xxxxxxV2 | Switch, dual pole double throw, separate symbols
U1 | 1 | ~ | 6116 | Package_DIP:DIP-24_W15.24mm_Socket
U2 | 1 | Pico | Pico | MCU_RaspberryPi_and_Boards:RPi_Pico_SMD_TH
U3, U5 | 2 | 74LS373 | 74LS373 | Package_DIP:DIP-20_W7.62mm | 8-bit Register, 3-state outputs
U4 | 1 | MICROSD_SPI_OR_SDIO_CARD | MICROSD_SPI_OR_SDIO_CARD | MICROSD_SPI_OR_SDIO_CARD:MODULE_MICROSD_SPI_OR_SDIO_CARD
UP1 | 1 | SW_Push | SW_Push | Button_Switch_THT:SW_PUSH_6mm | Push button switch, generic, two pins

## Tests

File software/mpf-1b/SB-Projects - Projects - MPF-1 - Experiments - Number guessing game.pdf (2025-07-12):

# Number Guessing Game

For this experiment I've created a simple number guessing game. The object of this game is to guess a number between 0 and 1023 (inclusive). Once you've guessed it correctly it is the MPF-1's turn to guess a number in the same range which you have come up with.

If you study the program listing of this experiment you can learn some very common practices in micro processor assembly programming: Decimal to binary conversion, binary to decimal conversion, leading zero suppression, random number generation and successive approximation, to name but a few.

After downloading the software package you can play the mp3 file to the MPF-1 by using file name 0007.

# User Guide

The operation of the program is divided into two sections. In the first section it's your turn to try to guess a number between 0 and 1023 (inclusive) which the MPF-1 has picked randomly. After each guess the MPF-1 tells you whether you should try a higher number (indicated by an H following your guess), or whether you should try a lower number (indicated by an L). Once you've guessed the secret number correctly the MPF-1 tells you how many guesses it took you to get it right.
Simply enter your guess and press GO to see if you've guessed correctly. If you make a typing error while entering the number you can clear the entire number by pressing DEL after which you can restart typing your correct guess.
The program allows you to enter values higher than 1023, which of course will always result in an L shown after your guess. Numbers above 65535 will result in an error because that is the maximum value a 16-bit number can hold.
Once you've guessed the number correctly the display will show "Yes.", followed by the number of tries.

After you've guessed the number correctly you press GO to enter the second stage of the program. Now it's your turn to think of a secret number in the range of 0 and 1023, and the MPF-1 will try to guess it. After the MPF-1 shows its guess you tell it whether it should guess higher (by pressing the + key), or whether it should guess lower (by pressing the - key). When the MPF-1 has guessed your secret number correctly you press the GO key and then you'll see how many guesses the MPF-1 needed.
Pressing GO once more will restart the program from the beginning.

You can restart the game at any time by pressing REG , after which it will be your turn to guess a newly picked secret number again. When it's your turn you may give up and let the MPF-1 guess your secret number by pressing DATA .

TIP: You can cheat by pressing PC when it's your turn to guess a number. The secret number will be displayed as long as you hold the key down.

# Operation

There are many things you can learn by studying the source code of this program. I've already mentioned a few, like: Decimal to binary and binary to decimal conversion, leading zero suppression, random number generation and successive approximation.

SB-Projects - Projects - MPF-1 - Experiments - Number guessing game | https://www.sbprojects.net/projects/mpf1/guess.php
1 of 2 | 7/7/2025, 8:38 PM

Maybe the successive approximation deserves a bit more explanation here.

Successive approximation is often used to convert an analog signal to digital. We are not going to convert an analog signal to digital here, however we're going to use a similar technique.
The principle behind it is quite simple. When we want to guess a number in a predefined range we simply split that range in half and make our first guess right in the middle. If we are instructed to guess higher we split the new range (from half way to the top) in the middle again. If we are instructed to guess lower we split the new range (from the bottom to half way) in the middle again. This process is repeated until we are informed that we've found the correct number, or until we can't split the range in two any longer.
In software this is fairly easy, as long as we stick to maximum numbers which are a power of 2. In our program we use 10 to the power of 2 (minus 1) as maximum number, which is a 10 bit number. Our first guess is now simply 1000000000B

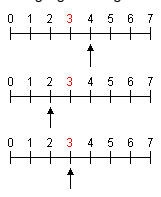
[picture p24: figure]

(which is 512 in decimal). If we should guess higher we leave that "1" bit where it is, if we should guess lower we clear it to "0" again. Then we shift our mask 1 bit to the right and add it to the previous result, this makes our next guess. This continues until the mask becomes 0 or until we've struck gold earlier.
What would be the maximum number of guesses the computer would need to guess any number you come up with in the given range? Is it a surprise that this maximum number is 10 for a 10-bit number?

Well, there is a slight catch. There is one exception, and that is when you want the computer to guess 0. A range with an even number of integers can not be split right in the middle without getting a fraction. Actually with a 10-bit range 511.5 should be our first guess. This is not appropriate, therefore we'll compromise by starting at 512. However this means that it would take 11 guesses only if the target value is 0.
Try to figure this out from the diagram in the picture above. In this 3-bit example you would normally need a maximum of 3 guesses. However it requires 4 guesses to get to 0.

# Room For Improvement

As always there are some things you can alter to this program to improve it, or to adapt it to your own ideas. Changing existing programs is a great way of teaching yourself the assembly skills.

- You can alter the program to get different maximum values.
- What would be the easiest way to change the range from 1 to 1024 instead of 0 to 1023?
- You may give some penalty points to the human guesser when he or she cheated!
- When you let the MPF-1 guess a secret number of 0 it will tell you that it needed 10 guesses to get it. However this is wrong, in fact it needed 11 guesses. I didn't bother about that, but it's a good exercise for you to correct this.

# Download

Here you can download the file guess.zip (guess.zip), (https://www.sbprojects.net/projects/mpf1/guess.zip) which contains the source listing, the actual plain hex file, a list file and an mp3 file of the program.

SB-Projects - Projects - MPF-1 - Experiments - Number guessing game | https://www.sbprojects.net/projects/mpf1/guess.php
2 of 2 | 7/7/2025, 8:38 PM

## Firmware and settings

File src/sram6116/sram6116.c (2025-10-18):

#include <stdio.h>
#include <stdlib.h>
#include <stdint.h>
#include <stdarg.h>


#include "hardware/vreg.h"

#include "pico/stdlib.h"
#include "pico/multicore.h"
#include "ssd1306_i2c.c"
#include "sd_card.h"
#include "ff.h"
#include "hardware/adc.h"
#include "pico/time.h"
#include "hardware/pwm.h"
#include "hardware/clocks.h"
#include "hardware/spi.h"

//
//
//

#define VERSION " v1.2  (C) 2025 "

//
// ADC Configuration (MPF.INI file!) 
// 

#define FILE_LENGTH 17
#define FILE_BUFF_SIZE 20
#define FILE_EXT "*.MPF" 

//
//
//

#define ADC_DEBUG_DELAY 100

volatile bool DEBUG_ADC = false;
volatile bool TUNE_ADC = false; 

volatile char MACHINE[FILE_LENGTH] = "MPF-1P";
volatile char BANK_PROG[4][FILE_LENGTH]; 

volatile uint16_t CANCEL2_ADC = 0xF00; 
volatile uint16_t CANCEL_ADC  = 0xD80; 
volatile uint16_t OK_ADC      = 0xC00; 
volatile uint16_t BACK_ADC    = 0x800; 
volatile uint16_t DOWN_ADC    = 0x500; 
volatile uint16_t UP_ADC      = 0x200; 

//
//
//

#define byte uint8_t

#define DISPLAY_DELAY       200
#define DISPLAY_DELAY_LONG  500
#define DISPLAY_DELAY_SHORT 100

#define BLINK_DELAY (100 * 1000) 
#define LONG_BUTTON_DELAY (400 * 1000) 

typedef char display_line[17];
display_line file;

const char* hexStringChar[] = {"0", "1", "2", "3", "4", "5", "6", "7", "8", "9", "a", "b", "C", "d", "E", "F" };

#define TEXT_BUFFER_SIZE 256
char text_buffer[TEXT_BUFFER_SIZE]; 

char line1[TEXT_BUFFER_SIZE]; 
char line2[TEXT_BUFFER_SIZE]; 
char line3[TEXT_BUFFER_SIZE]; 
char line4[TEXT_BUFFER_SIZE]; 

#define LINES 4
char *screen[LINES] = {line1, line2, line3, line4}; 

//
//
//

#define PICO_DEFAULT_I2C_SDA_PIN 20
#define PICO_DEFAULT_I2C_SCL_PIN 21

#define ADR_INPUTS_START 2
#define DATA_GPIO_START (ADR_INPUTS_START + 6)
#define DATA_GPIO_END (DATA_GPIO_START + 8) 

#define SEL1 0
#define SEL2 1 
#define RESET_PIN 28

#define CE_INPUT 26
#define WE_INPUT 22

#define ADC_KEYS_INPUT 27

const uint LED_PIN = PICO_DEFAULT_LED_PIN;

//
//
//

#define MAX_BANKS 0x4

static uint8_t cur_bank = 0; 

uint8_t ram[MAX_BANKS][(uint32_t) 2048] = {};
uint8_t sdram[(uint32_t) 2048] = {};

//
// 
// 

volatile bool disabled = false;
volatile bool read = false; 
volatile bool written = false; 
volatile bool confirmed = false; 

uint32_t addr_mask = 0; 
uint32_t data_mask = 0; 
uint32_t gpio = 0; 

uint32_t low_adr = 0; 
uint32_t high_adr = 0; 

uint32_t m_adr = 0; 
uint32_t r_op = 0; 
uint32_t w_op = 0; 

uint32_t d_adr = 0; 
uint32_t dr_op = 0; 
uint32_t dw_op = 0; 

//
// Utilities 
//

unsigned char decode_hex(char c) {
  if (c >= 65 && c <= 70)
    return c - 65 + 10;
  else if (c >= 97 && c <= 102)
    return c - 97 + 10;
  else if(c >= 48 && c <= 67)
    return c - 48;
  else
    return -1;
}

unsigned char reverse_bits(unsigned char b) {
  return (b & 0b00000001) << 3 |  (b & 0b00000010) << 1 | (b & 0b00000100) >> 1 |  (b & 0b00001000) >> 3 | 
    (b & 0b00010000) << 3 |  (b & 0b00100000) << 1 | (b & 0b01000000) >> 1 |  (b & 0b10000000) >> 3 ; 
}

void clear_bank(uint8_t bank) {
  for (uint32_t adr = 0; adr < 2048; adr++) {
    ram[bank][adr] = 0; 
  }
  memset(BANK_PROG[bank], 0, FILE_LENGTH);

} 

//
// Display
//

void clear_screen() {
  memset(buf, 0, SSD1306_BUF_LEN);
  render(buf, &frame_area);
  memset(line1, 0, TEXT_BUFFER_SIZE);
  memset(line2, 0, TEXT_BUFFER_SIZE);
  memset(line3, 0, TEXT_BUFFER_SIZE);
  memset(line4, 0, TEXT_BUFFER_SIZE);
}

void clear_screen0() {
  memset(buf, 0, SSD1306_BUF_LEN);
  memset(line1, 0, TEXT_BUFFER_SIZE);
  memset(line2, 0, TEXT_BUFFER_SIZE);
  memset(line3, 0, TEXT_BUFFER_SIZE);
  memset(line4, 0, TEXT_BUFFER_SIZE);
}

void clear_line0(int line) {
  switch (line) {
  case 0 : memset(line1, 0, TEXT_BUFFER_SIZE); break; 
  case 1 : memset(line2, 0, TEXT_BUFFER_SIZE); break;
  case 2 : memset(line3, 0, TEXT_BUFFER_SIZE); break; 
  case 4 : memset(line4, 0, TEXT_BUFFER_SIZE); break;
  }
  strcpy(screen[line],  "                "); 
  WriteString(buf, 0, line*8, screen[line]);
}

void clear_line(int line) {
  clear_line0(line);
  render(buf, &frame_area); 
}

void print_string0(int x, int y, char* text, ...) {

  va_list args;
  va_start(args, text); 
  vsnprintf(text_buffer, TEXT_BUFFER_SIZE, text, args); 
  strcpy(screen[y], text_buffer); 
  WriteString(buf, x*8, y*8, text_buffer);
  va_end(args);
}

void print_string(int x, int y, char* text, ...) {
  va_list args;
  va_start(args, text); 
  vsnprintf(text_buffer, TEXT_BUFFER_SIZE, text, args); 
  strcpy(screen[y], text_buffer); 
  WriteString(buf, x*8, y*8, text_buffer);
  render(buf, &frame_area); 
}

void print_line(int x, char* text, ...) {    
  va_list args;
  va_start(args, text); 
  vsnprintf(text_buffer, TEXT_BUFFER_SIZE, text, args); 
  char* screen0 = screen[0]; 
  for (int i = 0; i < 3; i++) {
    screen[i] = screen[i+1];
    WriteString(buf, x*8, i*8, screen[i]); 
  }
  screen[3] = screen0; 
  strcpy(screen[3], text_buffer);     
  WriteString(buf, x*8, 3*8, text_buffer);
  render(buf, &frame_area); 
  va_end(args);
}

void print_line0(int x, char* text, ...) {    
  va_list args;
  va_start(args, text); 
  vsnprintf(text_buffer, TEXT_BUFFER_SIZE, text, args); 
  char* screen0 = screen[0]; 
  for (int i = 0; i < 3; i++) {
    screen[i] = screen[i+1];
    WriteString(buf, x*8, i*8, screen[i]); 
  }
  screen[3] = screen0; 
  strcpy(screen[3], text_buffer);     
  WriteString(buf, x*8, 3*8, text_buffer);
  va_end(args);
}

void print_char0(int x, int y, char c) {
  text_buffer[0] = c;
  text_buffer[1] = 0; 
  WriteString(buf, x*8, y*8, text_buffer);
}

void print_char(int x, int y, char c) {
  text_buffer[0] = c; 
  text_buffer[1] = 0; 
  WriteString(buf, x*8, y*8, text_buffer);
  render(buf, &frame_area); 
}

void disp_plot0(int x, int y) {
  SetPixel(buf, x, y, true);
}

void disp_plot(int x, int y) {
  SetPixel(buf, x, y, true);
  render(buf, &frame_area); 
}

void disp_line0(int x1, int y1, int x2, int y2 ) {
  DrawLine(buf, x1, y1, x2, y2, true);
}

void disp_line(int x1, int y1, int x2, int y2 ) {
  DrawLine(buf, x1, y1, x2, y2, true);
  render(buf, &frame_area); 
}

void render_display() {    
  render(buf, &frame_area); 
}

//
// UI Buttons 
//

volatile uint16_t adc = 0;

typedef enum { NONE, UP, DOWN, BACK, OK, CANCEL, CANCEL2 } button_state; 

uint32_t avg(uint32_t a, uint32_t b) {

  if (a == 0) {
    return b; 
  } else if (b == 0) {
    return a;
  } else {
    return ( a + b ) / 2;     

  }
  
}

uint32_t max(uint32_t a, uint32_t b) {

  return a > b ? a : b; 
  
}

uint32_t min(uint32_t a, uint32_t b) {

  return a < b ? a : b; 
  
}


bool some_button_pressed(void) {

  adc_select_input(1); 
  adc = adc_read();

  return adc <= 0xfe0; 

}

button_state read_button_state(void) { 

  adc_select_input(1); 
  adc = adc_read();
  
  if (adc <= UP_ADC) {
    return UP; 
  } else if (adc <= DOWN_ADC) {
    return DOWN; 
  } else if (adc <= BACK_ADC) { 
    return BACK; 
  } else if (adc <= OK_ADC) {
    return OK; 
  } else if (adc <= CANCEL_ADC) {
    return CANCEL; 
  } else if (adc <= CANCEL2_ADC) {
    return CANCEL2; 
  } else {
    return NONE; 
  }

}

bool wait_for_button_release(void) {
  uint64_t last = time_us_64(); 
  while (read_button_state() != NONE) {}
  return (time_us_64() - last > LONG_BUTTON_DELAY); 
}

void wait_for_button(void) {
  while (read_button_state() == NONE) {}
  wait_for_button_release(); 
  return;
}

bool wait_for_button_release_raw(void) {
  adc_select_input(1); 
  do {
    adc = adc_read();
  } while (adc < 0xFE0);

  sleep_ms(500);
  
}

void wait_for_button_raw(void) {
  adc_select_input(1); 
  do {
    adc = adc_read();
  } while (adc > 0xFE0);

  uint32_t adc0 = adc;
  
  wait_for_button_release_raw();

  adc = adc0;
  
  return;
}

bool wait_for_yes_no_button(void) {
  button_state button; 
  while (true) {
    button = read_button_state();
    if (button == OK) {
      wait_for_button_release(); 
      return true;
    } else if (button == CANCEL || button == CANCEL2) {
      wait_for_button_release(); 
      return false;
    }
  }
}

//
// UI Display Loop 
//

typedef enum { OFF, ON } disp_mode; 

void display_loop() {    

  disp_mode cur_disp_mode = ON; 
  button_state buttons = NONE; 

  //
  //
  //

  if (TUNE_ADC) {

    reset_hold(); 
    clear_screen();       

    adc_select_input(1); 
    print_string(0,0,"BUTTON TUNING ");   
    print_string(0,1,"----------------");
    wait_for_button_release_raw();
    sleep_ms(DISPLAY_DELAY_LONG); 
    sleep_ms(DISPLAY_DELAY_LONG); 

    CANCEL_ADC = 0;
    uint32_t CANCEL_ADC_MIN = 0xFFF; 
    for (int i = 1; i < 6; i++) {
      print_string(0,2,"PUSH CANCEL (%d) ", i);
      wait_for_button_raw(); 
      print_string(0,3,"ADC:%03x", adc);
      CANCEL_ADC = max(adc, CANCEL_ADC);
      CANCEL_ADC_MIN = min(adc, CANCEL_ADC_MIN);
    }
    CANCEL2_ADC = avg(CANCEL_ADC, 0xFFF); 
    
    OK_ADC = 0;
    uint32_t OK_ADC_MIN = 0xFFF; 
    for (int i = 1; i < 6; i++) {
      print_string(0,2,"PUSH OK (%d)     ", i);
      wait_for_button_raw(); 
      print_string(0,3,"ADC:%03x", adc);
      OK_ADC = max(adc, OK_ADC);
      OK_ADC_MIN = min(adc, OK_ADC_MIN);
    }
    OK_ADC = avg(OK_ADC, CANCEL_ADC_MIN); 

    BACK_ADC = 0;
    uint32_t BACK_ADC_MIN = 0xFFF; 
    for (int i = 1; i < 6; i++) {
      print_string(0,2,"PUSH NXT/PRV (%d)", i);
      wait_for_button_raw(); 
      print_string(0,3,"ADC:%03x", adc);
      BACK_ADC = max(adc, BACK_ADC); 
      BACK_ADC_MIN = min(adc, BACK_ADC_MIN);
    }
    BACK_ADC = avg(BACK_ADC, OK_ADC_MIN); 

    DOWN_ADC = 0;
    uint32_t DOWN_ADC_MIN = 0xFFF; 
    for (int i = 1; i < 6; i++) {
      print_string(0,2,"PUSH DOWN (%d)   ", i);
      wait_for_button_raw(); 
      print_string(0,3,"ADC:%03x", adc);
      DOWN_ADC = max(adc, DOWN_ADC); 
      DOWN_ADC_MIN = min(adc, DOWN_ADC_MIN);
    }
    DOWN_ADC = avg(DOWN_ADC, BACK_ADC_MIN); 

    UP_ADC = 0;
    for (int i = 1; i < 6; i++) {
      print_string(0,2,"PUSH UP (%d)     ", i);
      wait_for_button_raw(); 
      print_string(0,3,"ADC:%03x", adc);
      UP_ADC = max(adc, UP_ADC); 
    }
    UP_ADC = avg(UP_ADC, DOWN_ADC_MIN); 

    clear_screen();       
    print_string(0,0,"TUNING COMPLETE!");
    print_string(0,1,"----------------");
    print_string(0,2,"Save ADC.INI?");
    if (! wait_for_yes_no_button()) {
      print_string(0,3,"*** CANCELED ***");
      sleep_ms(DISPLAY_DELAY);
      sleep_ms(DISPLAY_DELAY);
      sleep_ms(DISPLAY_DELAY);
      return;
    } else {
      save_buttons_config_file(); 
    }
  } 

  //
  //
  //

  if (DEBUG_ADC) {

    reset_hold(); 
    clear_screen(); 	  

    while (true) {
      adc_select_input(1); 
      print_string(0,1,"ADC:%03x       ", adc_read());
      sleep_ms(ADC_DEBUG_DELAY);       
    }    
  }

  //
  //
  // 
  
  while (true) {

    //
    //
    //

    /* 
       if (cur_disp_mode != OFF) { 

       sprintf(text_buffer, "%1x:%04x O:%02x I:%02x", cur_bank, d_adr, dr_op, dw_op); 
       WriteString(buf, 0, 0, text_buffer);
	            
       render(buf, &frame_area);
       } */ 

    //
    //
    //

    buttons = read_button_state(); 

    if (buttons != NONE ) {

      reset_hold(); 
      confirmed = false;
      disabled = true;

      // in case it is in the 2nd part of the busy loop... 
      read = true; 
      written = true;

      while (!confirmed) {};

      switch (buttons) {
      case UP: 
	// LOAD
	pgm1();
	sleep_ms(DISPLAY_DELAY);
	sleep_ms(DISPLAY_DELAY);
	if (cur_disp_mode == ON) 
	  show_info();
	else
	  clear_screen(); 	  

	break;
	
      case DOWN: 
	// SAVE
	pgm2();
	sleep_ms(DISPLAY_DELAY);
	sleep_ms(DISPLAY_DELAY);
	if (cur_disp_mode == ON) 
	  show_info();
	else
	  clear_screen(); 	  

	break;
	
      case BACK:
	// CHANGE CUR BANK

	cur_bank = (cur_bank + 1) % (MAX_BANKS);

	clear_screen();
	sprintf(text_buffer, "BANK #%1x", cur_bank); 
	WriteString(buf, 0, 0, text_buffer);
	render(buf, &frame_area);
	sleep_ms(DISPLAY_DELAY);
	sleep_ms(DISPLAY_DELAY);
	if (cur_disp_mode == ON) 
	  show_info();
	else
	  clear_screen(); 	  

	break;

      case OK:

	clear_screen();
	sprintf(text_buffer, "CLEAR BANK #%1x?", cur_bank); 
	WriteString(buf, 0, 0, text_buffer);
	render(buf, &frame_area);
	wait_for_button_release(); 

	if ( wait_for_yes_no_button()) {
	  clear_bank(cur_bank);
	  print_string(0,3,"CLEARED!");
	} else 
	  print_string(0,3,"CANCELED!");       

	sleep_ms(DISPLAY_DELAY);
	sleep_ms(DISPLAY_DELAY);
	if (cur_disp_mode == ON) 
	  show_info();
	else
	  clear_screen(); 	  
       
	break; 

      case CANCEL:
	
	if (cur_disp_mode == OFF ) 
	  cur_disp_mode = ON; 
	else
	  cur_disp_mode = OFF; 

	sleep_ms(DISPLAY_DELAY);
	sleep_ms(DISPLAY_DELAY);

	if (cur_disp_mode == ON) 
	  show_info();
	else
	  clear_screen(); 	  

	break;

      default :

	clear_screen();
	sprintf(text_buffer, "ADC #%1x KEY #%1x", adc, buttons); 
	WriteString(buf, 0, 0, text_buffer);
	print_string(0,1,"*  ADC GLITCH  *"); 
	print_string(0,2,"* BUTTON PRESS *"); 
	print_string(0,3,"* CONFIG ERROR *");
	render(buf, &frame_area);

	sleep_ms(DISPLAY_DELAY);
	sleep_ms(DISPLAY_DELAY);
	sleep_ms(DISPLAY_DELAY);
	sleep_ms(DISPLAY_DELAY);
	
      } 

      gpio_put(LED_PIN, 0);
      disabled = false;
      reset_release(); 

      
    }

  } 

}

//
// SD Card
//

int sd_test() {

  FRESULT fr;
  FATFS fs;
  FIL fil;
  int ret;
  char buf[FILE_BUFF_SIZE];
  char filename[] = "test02.txt";
    
  // Initialize SD card
  if (!sd_init_driver()) {
    print_string(0,0,"BAD SDCARD 1");
    while (true);
  }

  // Mount drive
  fr = f_mount(&fs, "0:", 1);
  if (fr != FR_OK) {
    print_string(0,0,"BAD SDCARD 2");
    while (true);
  }

  // Open file for writing ()
  fr = f_open(&fil, filename, FA_WRITE | FA_CREATE_ALWAYS);
  if (fr != FR_OK) {
    print_string(0,0,"BAD SDCARD 3");
    while (true);
  }

  // Write something to file
  ret = f_printf(&fil, "SD Card\r\n");
  if (ret < 0) {
    print_string(0,0,"BAD SDCARD 4");
    f_close(&fil);
    while (true);
  }
  ret = f_printf(&fil, "works without\r\n");
  if (ret < 0) {
    print_string(0,0,"BAD SDCARD 5");
    f_close(&fil);
    while (true);
  }

  ret = f_printf(&fil, "any problems!\r\n");
  if (ret < 0) {
    print_string(0,0,"BAD SDCARD 6");
    f_close(&fil);
    while (true);
  }

  ret = f_printf(&fil, "Cool!\r\n");
  if (ret < 0) {
    print_string(0,0,"BAD SDCARD 7");
    f_close(&fil);
    while (true);
  }

  // Close file
  fr = f_close(&fil);
  if (fr != FR_OK) {
    print_string(0,0,"BAD SDCARD 8");
    while (true);
  }

  // Open file for reading
  fr = f_open(&fil, filename, FA_READ);
  if (fr != FR_OK) {
    print_string(0,0,"BAD SDCARD 9");
    while (true);
  }

  // Print every line in file over serial
  clear_screen(); 
  int i = 0;
  
  while (f_gets(buf, sizeof(buf), &fil)) {
    // print_string(0, i++ , buf);
  }

  // Close file
  fr = f_close(&fil);
  if (fr != FR_OK) {
    print_string(0,0,"BAD SDCARD 10");
    while (true);
  }

  // Unmount drive
  f_unmount("0:");

}
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
int main() {

  // Set system clock speed.
  // 125 MHz

  set_sys_clock_pll(1100000000, 4, 1);
  
  //
  //
  //
    
  stdio_init_all();
  gpio_init(LED_PIN);
  gpio_set_dir(LED_PIN, GPIO_OUT);  

  //
  //
  //

  gpio_init(RESET_PIN);
  gpio_set_function(RESET_PIN, GPIO_FUNC_SIO); 
  reset_hold();   

  //
  //
  //

  adc_init();    
  adc_gpio_init(ADC_KEYS_INPUT);

  //
  //
  //

  ssd1306_setup();
  
  //
  //
  //

  cur_bank = 0; 
    
  for (uint8_t pgm = 0; pgm < MAX_BANKS; pgm++) {
    clear_bank(pgm); 
  }

  //
  //
  //
  

  for (gpio = ADR_INPUTS_START; gpio < DATA_GPIO_START; gpio++) {
    addr_mask |= (1 << gpio);
    gpio_init(gpio);
    gpio_set_function(gpio, GPIO_FUNC_SIO); 
    gpio_set_dir(gpio, GPIO_IN);
  }

  for (gpio = DATA_GPIO_START; gpio < DATA_GPIO_END; gpio++) {
    data_mask |= (1 << gpio);
    gpio_init(gpio);
    gpio_set_function(gpio, GPIO_FUNC_SIO); 
    gpio_set_dir(gpio, GPIO_IN);
  }

  gpio_init(SEL1);
  gpio_set_function(SEL1, GPIO_FUNC_SIO); 
  gpio_set_dir(SEL1, GPIO_OUT);
  gpio_set_outover(SEL1, GPIO_OVERRIDE_NORMAL);
  gpio_put(SEL1, 1);

  gpio_init(SEL2);
  gpio_set_function(SEL2, GPIO_FUNC_SIO); 
  gpio_set_dir(SEL2, GPIO_OUT);
  gpio_set_outover(SEL2, GPIO_OVERRIDE_NORMAL);
  gpio_put(SEL2, 1);

  gpio_init(WE_INPUT);
  gpio_set_function(WE_INPUT, GPIO_FUNC_SIO); 
  gpio_set_dir(WE_INPUT, GPIO_IN);
  gpio_set_inover(WE_INPUT, GPIO_OVERRIDE_NORMAL);

  gpio_init(CE_INPUT);
  gpio_set_function(CE_INPUT, GPIO_FUNC_SIO); 
  gpio_set_dir(CE_INPUT, GPIO_IN);
  gpio_set_inover(CE_INPUT, GPIO_OVERRIDE_NORMAL);

  //
  //
  //

  if ( some_button_pressed() ) {

    wait_for_button_release_raw(); 
    // do button tuning
    TUNE_ADC = true;    
    multicore_launch_core1(display_loop);
    
    while (true) {
      __asm volatile (" nop\n ");
    }

  }

  //
  //
  //

  sd_read_init();
  load_init_progs();

  show_logo();   
  sleep_ms(DISPLAY_DELAY_LONG); 
  sleep_ms(DISPLAY_DELAY_LONG); 

  show_info(); 

  //
  //
  // 


  m_adr = 0;
  r_op = 0;
  w_op = 0; 

  multicore_launch_core1(display_loop);

  //
  //
  // 

  read = false; 
  written = false; 
  confirmed = false; 

  gpio_set_dir_masked(data_mask, 0);

  reset_release();   

  while (true) {   
    
    if (disabled ) {
      gpio_put(LED_PIN, 1);
      confirmed = true;
      while (disabled ) {}; 
    }

    while ( gpio_get(CE_INPUT) && ! disabled ) { // 135 ns (11000.... high clock!)    
    
      gpio_put(SEL1, 0);
      low_adr = ((gpio_get_all() & addr_mask) >> ADR_INPUTS_START ) & 0b111111; // A0 - A5
      gpio_put(SEL1, 1);
    
      gpio_put(SEL2, 0);
      high_adr = (((gpio_get_all() & addr_mask) >> ADR_INPUTS_START ) & 0b011111) << 6; // A6 - A10
      gpio_put(SEL2, 1);

      m_adr = low_adr | high_adr;

    }

    //
    //
    //

    read = false; 
    written = false; 

    while ( ! gpio_get(CE_INPUT) && ! disabled ) { 

      if (! read && ! gpio_get(WE_INPUT)) {
	gpio_set_dir_masked(data_mask, 0);
	// wait until address is stable! ~80 ns or so...
	__asm volatile (" nop\n nop\n nop\n nop\n nop\n nop\n nop\n nop\n nop\n nop\n nop\n nop\n nop\n");
	r_op = (gpio_get_all() & data_mask) >> DATA_GPIO_START ;
	ram[cur_bank][m_adr] = r_op;
	read = true;  
      } else if (! written) {
	w_op = ram[cur_bank][m_adr];   
	gpio_set_dir_masked(data_mask, data_mask);	
	gpio_put_masked(data_mask, (w_op << DATA_GPIO_START));
	written = true;
      }
    }
    
    gpio_set_dir_masked(data_mask, 0);

  }
}
 

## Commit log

2023-12-27 Initial commit - README later.
    [PicoRAM6116-B_Cu.gbr, PicoRAM6116-B_Mask.gbr, PicoRAM6116-B_Paste.gbr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]
2023-12-27 Adding Gerbers.zip file.
2024-02-26 Adding demo video - MPF-1B Towers of Hanoi assembler programming sessions.
2024-04-13 MPF-1P Towers of Hanoi Printer Demo
2024-04-13 Adding MPF-1P Demo video link to README - Towers of Hanoi with PicoRAM 6116 and Printer
2024-05-31 Software 6116.INI files updated - works perfectly with my MPF-1B and MPF-1P now. Button tuning. May be different for yours. I use a 9V PSU.
2025-10-18 Firmware v1.2. ADC button config error display.
    [sram6116.c]
2025-10-18 6116.INI threshold change (for my boards - yours might require different thresholds)
